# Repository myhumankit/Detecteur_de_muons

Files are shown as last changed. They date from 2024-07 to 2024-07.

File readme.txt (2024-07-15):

This project is an evolution of "CosmicWatch-Desktop-Muon-Detector" published by MIT.
see project description on . 
http://www.cosmicwatch.lns.mit.edu/detector#cosmicwatch

here, the aim was to develop a version of the sensor to support a participatory science program, 
so that it could be taken on board a sailing boat during high-latitude measurement campaigns. 

This new version, developed by My Human Kit , has made it possible to produce and significantly improve the architecture of the sensor 
and its code:
- Evolution of the code so that it can both record data and display it on an OLED screen (whereas MIT proposed 2 different versions of the code). 
- Addition of a GNSS receiver to synchronize data and autonomously record the boat's position 
- Addition of a RTC module to retain date and time in the event of a power cut 
- Improved data display on screen
- Optimization of the detection algo 
- Creation of a python script for data analysis (not yet finished)

my human kit, in carrying out this project, has supported the Astrolabe Expéditions association as part of the "cosmic sail" program.

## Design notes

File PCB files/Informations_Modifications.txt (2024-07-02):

le 19-02-2024
La version "Prod" est celle qui à été envoyée pour la réalisation des pcb.
La version "Fichiers_Eclates" est la version qui à servi à la réalisation des deux boitiers.
Les modifications concernes principalement le schéma et la carte ESP32.

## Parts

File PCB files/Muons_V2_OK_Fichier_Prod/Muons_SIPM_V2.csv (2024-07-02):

Source: | Muons_SIPM_V2 |  |  |  |  |  | Commentaires
Date: | 19/03/2023 14:07:50
Tool: | Eeschema 7.0.1
Generator: | P:\PCB\KiCad60\bin\scripting\plugins/bom_csv_grouped_by_value_with_fp.py
Component Count: | 140
Ref | Qnty | Value | Cmp name | Footprint | Description | Vendor
B1, | 1 | Blindage | Blindage_29.5 | COMPOSANT_CF:Blindage_29.5 | Blindage 29.5v
C1, C3, C5, C7, C8, C11, C14, | 7 | 0.1µF | C_Small | COMPOSANT_CF:C_0805_Muons | Unpolarized capacitor, small symbol
C2, C9, C24, | 3 | 1µF | C_Small | COMPOSANT_CF:C_0805_Muons | Unpolarized capacitor, small symbol
C4, | 1 | 22pF | C_Small | COMPOSANT_CF:C_0805_Muons | Unpolarized capacitor, small symbol
C6, | 1 | 0.47µF | C_Small | COMPOSANT_CF:C_0805_Muons | Unpolarized capacitor, small symbol
C10, C15, C17, C19, C20, C21, C22, | 7 | 10µF | C_Small | COMPOSANT_CF:C_0805_Muons | Unpolarized capacitor, small symbol
C12, | 1 | 10pF | C_Small | COMPOSANT_CF:C_0805_Muons | Unpolarized capacitor, small symbol
C13, | 1 | 20nF | C_Small | COMPOSANT_CF:C_0805_Muons | Unpolarized capacitor, small symbol
C16, C18, C23, C25, C26, | 5 | 100nF | C_Small | COMPOSANT_CF:C_0805_Muons | Unpolarized capacitor, small symbol
Cn1, | 1 | GND | TestPoint | COMPOSANT_CF:TestPoint_THTPad_4.75x3.7mm_Drill1.5mm | test point
D1, D2, D3, | 3 | D_Schottky | D_Schottky | Diode_SMD:D_SOD-123 | Schottky diode
D4, D5, D6, | 3 | MDB301 | MDB301 | Package_TO_SOT_SMD:SOT-23 | 30V 0.1A Small signal Schottky diode, SOT-23
H1, H2, | 2 | SiMP | MountingHole_Pad | MountingHole:MountingHole_2.2mm_M2_DIN965_Pad_TopBottom | Mounting Hole with connection
H3, H4, H5, H6, | 4 | Board_SiMP | MountingHole_Pad | MountingHole:MountingHole_2.2mm_M2_DIN965_Pad_TopBottom | Mounting Hole with connection
H7, H8, H9, H13, H14, | 5 | ESP | MountingHole_Pad | MountingHole:MountingHole_2.2mm_M2_DIN965_Pad_TopBottom | Mounting Hole with connection
H10, H11, H12, | 3 | RTC | MountingHole_Pad | MountingHole:MountingHole_2.2mm_M2_DIN965_Pad_TopBottom | Mounting Hole with connection
IC1, | 1 | BMP280_AZ | BMP280_AZ | COMPOSANT_CF:BMP280_AZ | Pressure Sensor Development Tools Barometric Pressure & Altitude Sensor
J1, | 1 | WM17457-ND | Conn_02x03_Odd_Even | Connector_PinSocket_2.54mm:PinSocket_2x03_P2.54mm_Vertical | Generic connector, double row, 02x03, odd/even pin numbering scheme (row 1 odd numbers, row 2 even numbers), script generated (kicad-library-utils/schlib/autogen/connector/)
J2, J4, | 2 | 221790-1 | 221790-1_1 | COMPOSANT_CF:TE_221790-1
J3, | 1 | DB9 F Chassi | DE9_Receptacle | Connector_Dsub:DSUB-9_Female_Horizontal_P2.77x2.84mm_EdgePinOffset4.94mm_Housed_MountingHolesOffset7.48mm | 9-pin female receptacle socket D-SUB connector, Mounting Hole
J5, | 1 | Conn_01x07_Socket | Conn_01x07_Socket | Connector_Molex:Molex_KK-254_AE-6410-07A_1x07_P2.54mm_Vertical | Generic connector, single row, 01x07, script generated
J6, | 1 | Conn_01x06_Socket | Conn_01x06_Socket | Connector_Molex:Molex_KK-254_AE-6410-06A_1x06_P2.54mm_Vertical | Generic connector, single row, 01x06, script generated
J7, | 1 | Conn_01x08_Socket | Conn_01x08_Socket | Connector_Molex:Molex_KK-254_AE-6410-08A_1x08_P2.54mm_Vertical | Generic connector, single row, 01x08, script generated
J8, | 1 | Depuis le board SIPM | Conn_01x08_Socket | Connector_Molex:Molex_KK-254_AE-6410-08A_1x08_P2.54mm_Vertical | Generic connector, single row, 01x08, script generated
J9, | 1 | Depuis le board SIPM | Conn_01x03_Socket | Connector_Molex:Molex_KK-254_AE-6410-03A_1x03_P2.54mm_Vertical | Generic connector, single row, 01x03, script generated
J10, | 1 | Vers Pcb GPS | Conn_01x06_Socket | Connector_Molex:Molex_KK-254_AE-6410-06A_1x06_P2.54mm_Vertical | Generic connector, single row, 01x06, script generated
J11, | 1 | Vers Pcb Gps | Conn_01x07_Socket | Connector_Molex:Molex_KK-254_AE-6410-07A_1x07_P2.54mm_Vertical | Generic connector, single row, 01x07, script generated
J12, | 1 | Conn_01x08_Socket | Conn_01x08_Socket | Connector_PinSocket_2.54mm:PinSocket_1x08_P2.54mm_Vertical | Generic connector, single row, 01x08, script generated
J13, | 1 | Conn_01x08_Socket | Conn_01x08_Socket | Connector_PinHeader_2.54mm:PinHeader_1x08_P2.54mm_Vertical | Generic connector, single row, 01x08, script generated
J14, | 1 | Oled | Conn_01x04_Socket | COMPOSANT_CF:OLED_PCB | Generic connector, single row, 01x04, script generated
J15, | 1 | Micro_SD_Card | Micro_SD_Card | COMPOSANT_CF:SD-CARD_AZ | Micro SD Card Socket
K1, | 1 | G3VM-21GR1 | G3VM-21GR1 | COMPOSANT_CF:G3VM-21GR1
K2, | 1 | G3VM-41DY | G3VM-41DY | COMPOSANT_CF:RELAY_G3VM-41DY
K3, | 1 | G3VM-81UR | G3VM-81UR | COMPOSANT_CF:G3VM-81UR
L1, | 1 | Ferrite Bead | L | Resistor_SMD:R_0805_2012Metric_Pad1.20x1.40mm_HandSolder | Inductor
L2, | 1 | 47ÂµH | L | Resistor_SMD:R_1210_3225Metric_Pad1.30x2.65mm_HandSolder | Inductor
Led1, | 1 | Double Led | Double_Led | COMPOSANT_CF:Double_Led | Buzzer, polarized
M1, | 1 | DS3231 | DS3231 | COMPOSANT_CF:REG_DS3231_2023
M2, | 1 | ESP_WROOM_32_38b | ESP_WROOM_32 | COMPOSANT_CF:MODULE_ESP32-DEVKITC
Q1, | 1 | BMBT3904 | PMBT3904 | Package_TO_SOT_SMD:SOT-323_SC-70 | 0.8A Ic, 45V Vce, NPN Transistor, SOT-323
Q2, | 1 | BSS138 | BSS138 | Package_TO_SOT_SMD:SOT-23 | 50V Vds, 0.22A Id, N-Channel MOSFET, SOT-23
R1, R6, R10, R13, R14, R16, R17, R18, R19, R20, R21, | 11 | 10k | R_Small | COMPOSANT_CF:R_0805_Muons | Resistor, small symbol
R2, | 1 | 226k | R_Small | COMPOSANT_CF:R_0805_Muons | Resistor, small symbol
R3, R4, R8, R9, R12, R15, R23, R24, R26, R27, | 10 | 1k | R | COMPOSANT_CF:R_0805_Muons | Resistor
R5, | 1 | 7.5k | R_Small | COMPOSANT_CF:R_0805_Muons | Resistor, small symbol
R7, R22, R29, R30, R31, | 5 | 100k | R | COMPOSANT_CF:R_0805_Muons | Resistor
R11, | 1 | 4.7M | R_Small | COMPOSANT_CF:R_0805_Muons | Resistor, small symbol
R25, | 1 | 3.3k | R | COMPOSANT_CF:R_0805_Muons | Resistor
R28, | 1 | 4.7k | R | COMPOSANT_CF:R_0805_Muons | Resistor
R32, | 1 | 360 | R_Small | COMPOSANT_CF:R_0805_Muons | Resistor, small symbol
R33, R34, | 2 | 0 | R | COMPOSANT_CF:R_Shunt_0805_Muons | Resistor
R35, R36, R37, R38, | 4 | 47k | R | COMPOSANT_CF:R_0805_Muons | Resistor
R39, R40, | 2 | 330 | R_Small | COMPOSANT_CF:R_0805_Muons | Resistor, small symbol
RV1, RV2, | 2 | 4.7k | R_Potentiometer_Trim | Potentiometer_THT:Potentiometer_Bourns_3005_Horizontal | Trim-potentiometer
RV3, RV4, | 2 | 5k | R_Potentiometer_Trim | Potentiometer_SMD:Potentiometer_Bourns_3314G_Vertical | Trim-potentiometer
SW1, | 1 | Ajust_Time | SW_MEC_5G | Button_Switch_THT:SW_Tactile_SPST_Angled_PTS645Vx83-2LFS | MEC 5G single pole normally-open tactile switch
SW2, | 1 | SW_Coded_SH-7010 | SW_Coded_SH-7010 | COMPOSANT_CF:Nidec_Copal_SC-1110 | Rotary switch, 4-bit encoding, 10 positions, Real code
TP1, TP2, | 2 | s1 | TestPoint | COMPOSANT_CF:TestPoint_THTPad_4.75x3.7mm_Drill1.5mm | test point
TP3, | 1 | GND3 | TestPoint | COMPOSANT_CF:TestPoint_THTPad_4.75x3.7mm_Drill1.5mm | test point
TP4, TP5, TP6, TP7, | 4 | GND1 | TestPoint | COMPOSANT_CF:TestPoint_THTPad_4.75x3.7mm_Drill1.5mm | test point
TP8, | 1 | GND2 | TestPoint | COMPOSANT_CF:TestPoint_THTPad_4.75x3.7mm_Drill1.5mm | test point
U1, | 1 | LT3461 | LT3461 | Package_TO_SOT_SMD:TSOT-23-6 | 1.2MHz White LED Drivers with Built-in Schottky, ThinSOT-23-6
U2, | 1 | AD823A | AD823A | Package_SO:SOIC-8_3.9x4.9mm_P1.27mm | Dual Operational Amplifiers, DIP-8/SOIC-8/TSSOP-8/VSSOP-8
U3, U4, | 2 | LT1806 | LT1806 | Package_SO:SOIC-8_3.9x4.9mm_P1.27mm | Ultra-Low Offset/Drift, Low-Noise, Precision Amplifiers, SOIC-8
U5, | 1 | DS18B20 | DS18B20 | Package_TO_SOT_THT:TO-92_Inline | Programmable Resolution 1-Wire Digital Thermometer TO-92
U6, | 1 | NEO-M8N | NEO-M8N | MODULE_CF:GPS_NEO8 | GNSS Module NEO M8, VCC 2.7V to 3.6V
U7, | 1 | LM311 | LM311 | Package_SO:SOIC-8_3.9x4.9mm_P1.27mm | Voltage Comparator, DIP-8/SOIC-8
U8, | 1 | MAX988EUK+ | MAX988EUK+ | COMPOSANT_CF:SOT95P280X145-5N
U9, | 1 | GT1167 | GT1167 | COMPOSANT_CF:DIP-12_Convertisseur | Convertisseur de niveau logic 2 canaux 3v3 5v
U10, | 1 | ADC_Breakout_ADS1015 | ADC_Breakout_ADS1115 | MODULE_CF:ADS1115_Small_BreakBord
U11, | 1 | G3VM-101DR1 | G3VM-101DR1(TR05) | COMPOSANT_CF:G3VM-21GR1
U12, | 1 | Regul3.3v | Regul3.3v | COMPOSANT_CF:Regulateur | 1A Low Dropout regulator, positive, adjustable output, TO-252

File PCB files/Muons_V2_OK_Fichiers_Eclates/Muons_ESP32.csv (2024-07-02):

Source: | I:\PCB\KiCad\MUONS v2\Muons_V3\Muons_ESP32.kicad_sch
Date: | 30/04/2023 09:25:12
Tool: | Eeschema 7.0.1
Generator: | P:\PCB\KiCad51101\bin\scripting\plugins/bom_csv_grouped_by_value_with_fp.py
Component Count: | 48
Ref | Qnty | Value | Cmp name | Footprint | Description | Vendor
C19, C20, C21, C22, | 4 | 10µF | C_Small | COMPOSANT_CF:C_0805_Muons | Unpolarized capacitor, small symbol
C23, C25, C26, | 3 | 100nF | C_Small | COMPOSANT_CF:C_0805_Muons | Unpolarized capacitor, small symbol
C24, | 1 | 1µF | C_Small | COMPOSANT_CF:C_0805_Muons | Unpolarized capacitor, small symbol
H7, H8, H9, H14, | 4 | ESP | MountingHole_Pad | MountingHole:MountingHole_2.2mm_M2_DIN965_Pad_TopBottom | Mounting Hole with connection
H15, H16, | 2 | ESP | MountingHole_Pad_2 | COMPOSANT_CF:MountingHole_2.2mm_M2 | Mounting Hole with connection
J8, | 1 | Depuis le board SIPM | Conn_01x08_Socket | Connector_Molex:Molex_KK-254_AE-6410-08A_1x08_P2.54mm_Vertical | Generic connector, single row, 01x08, script generated
J9, | 1 | Depuis le board SIPM | Conn_01x03_Socket | Connector_Molex:Molex_KK-254_AE-6410-03A_1x03_P2.54mm_Vertical | Generic connector, single row, 01x03, script generated
J10, | 1 | Vers Pcb GPS | Conn_01x06_Socket | Connector_Molex:Molex_KK-254_AE-6410-06A_1x06_P2.54mm_Vertical | Generic connector, single row, 01x06, script generated
J11, | 1 | Vers Pcb Gps | Conn_01x07_Socket | Connector_Molex:Molex_KK-254_AE-6410-07A_1x07_P2.54mm_Vertical | Generic connector, single row, 01x07, script generated
J13, | 1 | Conn_01x08_Socket | Conn_01x08_Socket | Connector_PinHeader_2.54mm:PinHeader_1x08_P2.54mm_Vertical | Generic connector, single row, 01x08, script generated
Led1, | 1 | Double Led | Double_Led | COMPOSANT_CF:Double_Led | Buzzer, polarized
M2, | 1 | ESP_WROOM_32_38b_AZ | ESP_WROOM_32_38b_AZ | COMPOSANT_CF:MODULE_ESP32-DEVKITC
R27, | 1 | 1k | R | COMPOSANT_CF:R_0805_Muons | Resistor
R28, | 1 | 4.7k | R | COMPOSANT_CF:R_0805_Muons | Resistor
R29, R30, R31, | 3 | 100k | R | COMPOSANT_CF:R_0805_Muons | Resistor
R32, | 1 | 360 | R_Small | COMPOSANT_CF:R_0805_Muons | Resistor, small symbol
R33, R34, | 2 | 0 | R | COMPOSANT_CF:R_Shunt_0805_Muons | Resistor
R35, R36, R37, R38, | 4 | 47k | R | COMPOSANT_CF:R_0805_Muons | Resistor
R39, R40, | 2 | 330 | R_Small | COMPOSANT_CF:R_0805_Muons | Resistor, small symbol
R41, | 1 | 47k | R | COMPOSANT_CF:R_Shunt_0805_Muons | Resistor
RV4, | 1 | 5k | R_Potentiometer_Trim | Potentiometer_SMD:Potentiometer_Bourns_3314G_Vertical | Trim-potentiometer
SW1, | 1 | Ajust_Time | SW_MEC_5G | Button_Switch_THT:SW_Tactile_SPST_Angled_PTS645Vx83-2LFS | MEC 5G single pole normally-open tactile switch
SW2, | 1 | SW_Coded_SH-7010 | SW_Coded_SH-7010 | COMPOSANT_CF:Nidec_Copal_SC-1110 | Rotary switch, 4-bit encoding, 10 positions, Real code
SW3, | 1 | SW_SPDT | SW_SPDT | COMPOSANT_CF:Sw_sil | Switch, single pole double throw
TP4, TP5, TP6, TP7, | 4 | GND1 | TestPoint | COMPOSANT_CF:TestPoint_THTPad_4.75x3.7mm_Drill1.5mm | test point
U9, | 1 | GT1167 | GT1167 | COMPOSANT_CF:DIP-12_Convertisseur | Convertisseur de niveau logic 2 canaux 3v3 5v
U10, | 1 | ADC_Breakout_ADS1015 | ADC_Breakout_ADS1115 | MODULE_CF:ADS1115_Small_BreakBord
U11, | 1 | G3VM-41DY | TLP241 | COMPOSANT_CF:G3VM-21GR1
U12, | 1 | Regul3.3v | Regul3.3v | COMPOSANT_CF:Regulateur | 1A Low Dropout regulator, positive, adjustable output, TO-252

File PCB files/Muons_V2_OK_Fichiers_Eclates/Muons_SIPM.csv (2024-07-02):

Source: | I:\PCB\KiCad\MUONS v2\Muons_V3\Muons_SIPM.kicad_sch
Date: | 30/04/2023 09:02:18
Tool: | Eeschema 7.0.1
Generator: | P:\PCB\KiCad60\bin\scripting\plugins/bom_csv_grouped_by_value_with_fp.py
Component Count: | 75
Ref | Qnty | Value | Cmp name | Footprint | Description | Vendor
B1, | 1 | Blindage | Blindage_29.5 | COMPOSANT_CF:Blindage_29.5 | Blindage 29.5v
C1, C3, C5, C7, C8, C11, C14, | 7 | 0.1ÂµF | C_Small | COMPOSANT_CF:C_0805_Muons | Unpolarized capacitor, small symbol
C2, C9, | 2 | 1ÂµF | C_Small | COMPOSANT_CF:C_0805_Muons | Unpolarized capacitor, small symbol
C4, | 1 | 22pF | C_Small | COMPOSANT_CF:C_0805_Muons | Unpolarized capacitor, small symbol
C6, | 1 | 0.47ÂµF | C_Small | COMPOSANT_CF:C_0805_Muons | Unpolarized capacitor, small symbol
C10, C15, | 2 | 10ÂµF | C_Small | COMPOSANT_CF:C_0805_Muons | Unpolarized capacitor, small symbol
C12, | 1 | 10pF | C_Small | COMPOSANT_CF:C_0805_Muons | Unpolarized capacitor, small symbol
C13, | 1 | 4.7nF | C_Small | COMPOSANT_CF:C_0805_Muons | Unpolarized capacitor, small symbol
C16, | 1 | 100nF | C | COMPOSANT_CF:C_0805_Muons | Unpolarized capacitor
Cn1, | 1 | GND | TestPoint | COMPOSANT_CF:TestPoint_THTPad_4.75x3.7mm_Drill1.5mm | test point
D1, D2, | 2 | BAT54 | D_Schottky | Diode_SMD:D_SOD-123 | Schottky diode
D3, | 1 | D_Schottky | D_Schottky | Resistor_SMD:R_1206_3216Metric_Pad1.30x1.75mm_HandSolder | Schottky diode
D4, D5, D6, | 3 | MDB301 | MDB301 | Package_TO_SOT_SMD:SOT-23 | 30V 0.1A Small signal Schottky diode, SOT-23
H1, H2, | 2 | SiMP | MountingHole_Pad | MountingHole:MountingHole_2.2mm_M2_DIN965_Pad_TopBottom | Mounting Hole with connection
H3, H4, H5, H6, | 4 | Board_SiMP | MountingHole_Pad | MountingHole:MountingHole_2.2mm_M2_DIN965_Pad_TopBottom | Mounting Hole with connection
J1, | 1 | WM17457-ND | Conn_02x03_Odd_Even | Connector_PinSocket_2.54mm:PinSocket_2x03_P2.54mm_Vertical | Generic connector, double row, 02x03, odd/even pin numbering scheme (row 1 odd numbers, row 2 even numbers), script generated (kicad-library-utils/schlib/autogen/connector/)
J2, | 1 | 221790-1 | 221790-1 | COMPOSANT_CF:TE_221790-1
J7, | 1 | Conn_01x08_Socket | Conn_01x08_Socket | Connector_Molex:Molex_KK-254_AE-6410-08A_1x08_P2.54mm_Vertical | Generic connector, single row, 01x08, script generated
K1, | 1 | G3VM-21GR1 | G3VM-21GR1 | COMPOSANT_CF:G3VM-21GR1
K2, | 1 | G3VM-41DY | G3VM-41DY | COMPOSANT_CF:RELAY_G3VM-41DY
K3, | 1 | G3VM-81UR | G3VM-81UR | COMPOSANT_CF:G3VM-81UR
L1, | 1 | Ferrite Bead | L | Resistor_SMD:R_0805_2012Metric_Pad1.20x1.40mm_HandSolder | Inductor
L2, | 1 | 47ÂµH | L | Resistor_SMD:R_1210_3225Metric_Pad1.30x2.65mm_HandSolder | Inductor
Q1, | 1 | BMBT3904 | PMBT3904 | Package_TO_SOT_SMD:SOT-323_SC-70 | 0.8A Ic, 45V Vce, NPN Transistor, SOT-323
Q2, | 1 | BSS138 | BSS138 | Package_TO_SOT_SMD:SOT-23 | 50V Vds, 0.22A Id, N-Channel MOSFET, SOT-23
R1, R6, R13, R14, R16, R17, R18, | 7 | 10k | R_Small | COMPOSANT_CF:R_0805_Muons | Resistor, small symbol
R2, | 1 | 226k | R_Small | COMPOSANT_CF:R_0805_Muons | Resistor, small symbol
R3, R4, R8, R9, R15, R23, R24, R26, | 8 | 1k | R | COMPOSANT_CF:R_0805_Muons | Resistor
R5, | 1 | 7.5k | R_Small | COMPOSANT_CF:R_0805_Muons | Resistor, small symbol
R7, R22, | 2 | 100k | R | COMPOSANT_CF:R_0805_Muons | Resistor
R10, R19, R20, R21, | 4 | 470 | R_Small | COMPOSANT_CF:R_0805_Muons | Resistor, small symbol
R11, | 1 | 4.7M | R_Small | COMPOSANT_CF:R_0805_Muons | Resistor, small symbol
R12, R27, | 2 | 0 | R | COMPOSANT_CF:R_0805_Muons | Resistor
R25, | 1 | 3.3k | R | COMPOSANT_CF:R_0805_Muons | Resistor
RV3, | 1 | 5k | R_Potentiometer_Trim | Potentiometer_SMD:Potentiometer_Bourns_3314G_Vertical | Trim-potentiometer
U1, | 1 | LT3461 | LT3461 | Package_TO_SOT_SMD:TSOT-23-6 | 1.2MHz White LED Drivers with Built-in Schottky, ThinSOT-23-6
U2, | 1 | AD823A | AD823A | Package_SO:SOIC-8_3.9x4.9mm_P1.27mm | Dual Operational Amplifiers, DIP-8/SOIC-8/TSSOP-8/VSSOP-8
U3, U4, | 2 | LT1806 | LT1806 | Package_SO:SOIC-8_3.9x4.9mm_P1.27mm | Ultra-Low Offset/Drift, Low-Noise, Precision Amplifiers, SOIC-8
U5, | 1 | DS18B20 | DS18B20 | Package_TO_SOT_THT:TO-92_Inline | Programmable Resolution 1-Wire Digital Thermometer TO-92
U7, | 1 | LM311 | LM311 | Package_SO:SOIC-8_3.9x4.9mm_P1.27mm | Voltage Comparator, DIP-8/SOIC-8
U8, | 1 | MAX988EUK+ | MAX988EUK+ | COMPOSANT_CF:SOT95P280X145-5N

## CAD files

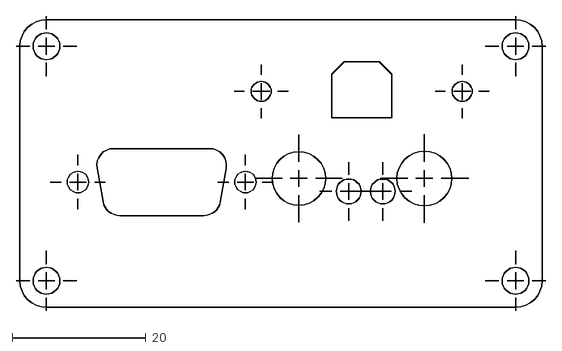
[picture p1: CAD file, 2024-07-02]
3D Models/Plaque_AR_V3_CNC.dxf
79.0 x 44.0

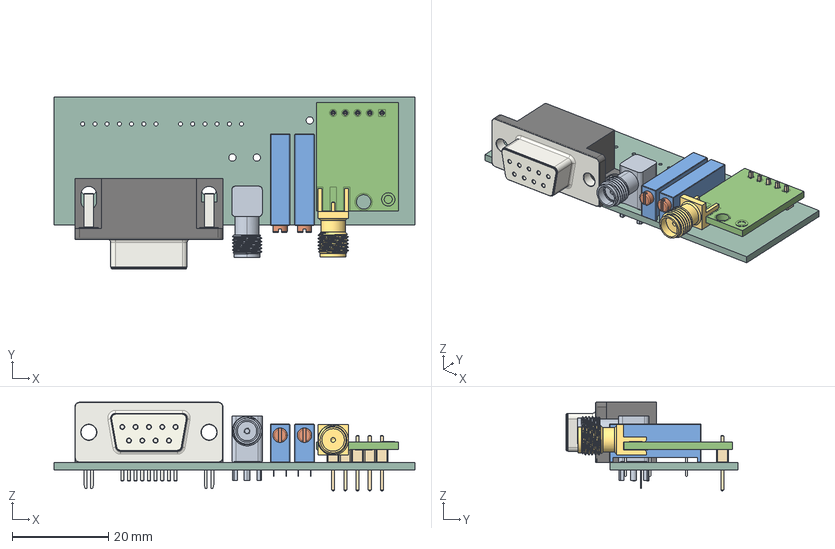
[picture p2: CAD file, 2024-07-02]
PCB files/Muons_V2_OK_Fichiers_Eclates/Muons_GPS.step
75.0 x 35.7 x 18.4 mm
PCB

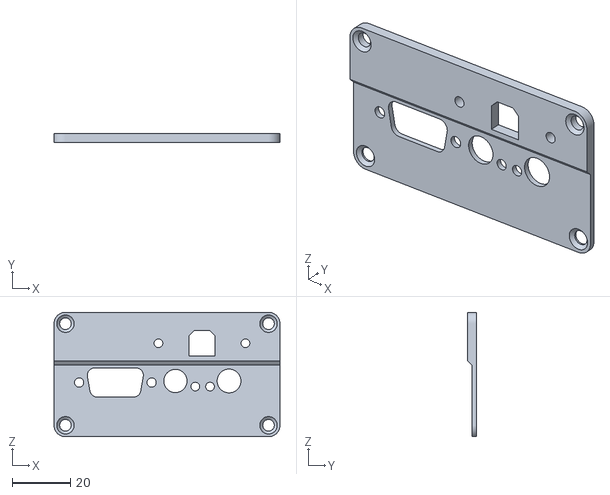
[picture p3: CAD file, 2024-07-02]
3D Models/Plaque_AR_V2.stl
77.9 x 3.00 x 42.9

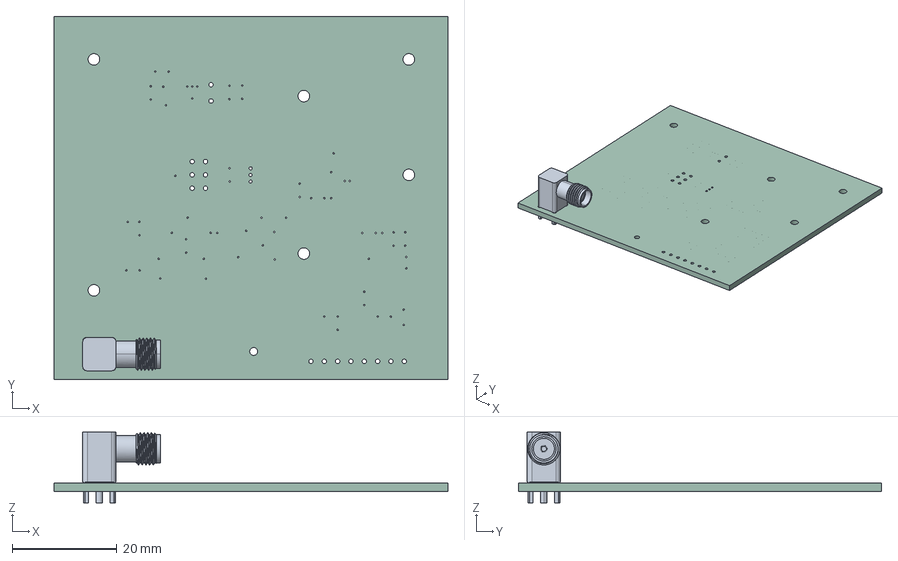
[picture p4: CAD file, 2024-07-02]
PCB files/Muons_V2_OK_Fichiers_Eclates/Muons_SIPM.step
75.0 x 69.2 x 13.5 mm
PCB

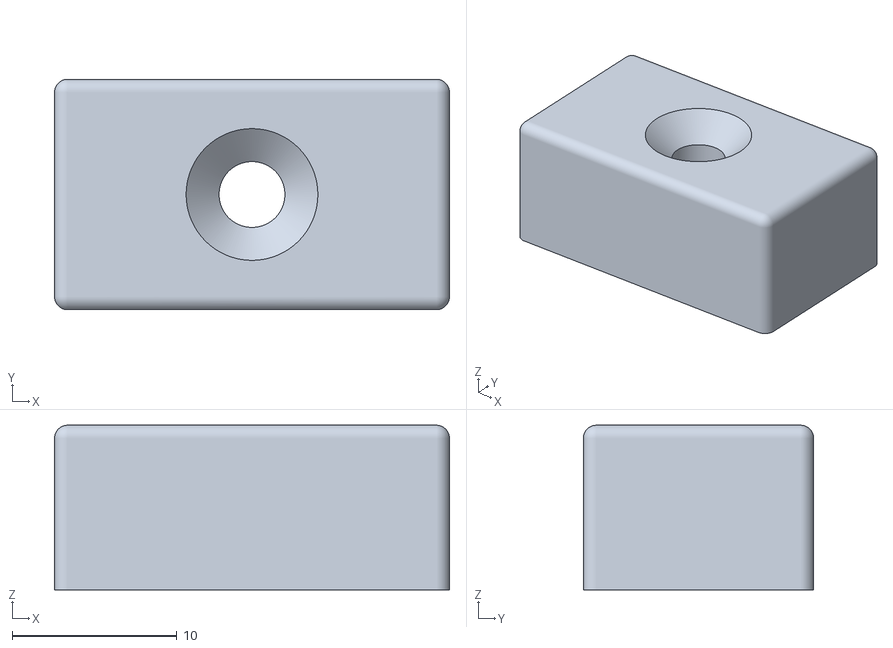
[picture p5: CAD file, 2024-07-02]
3D Models/Forme_Blindage.stl
24.0 x 14.0 x 10.0

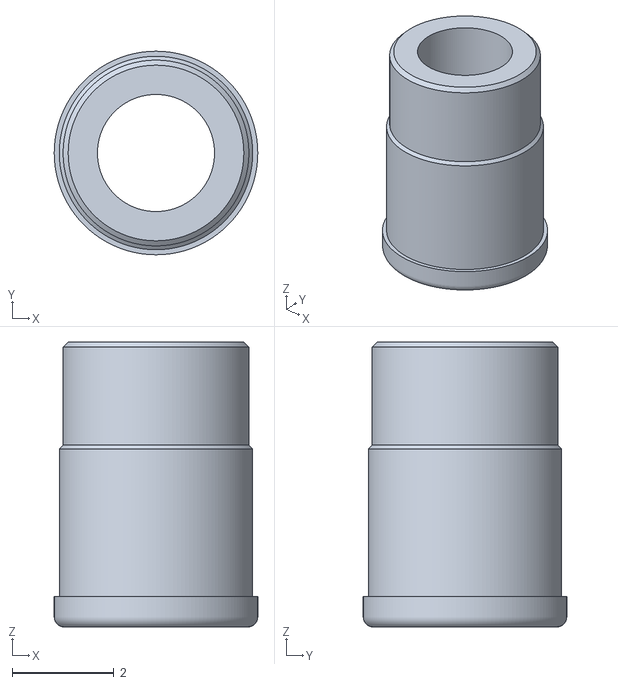
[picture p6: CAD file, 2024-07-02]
3D Models/Guide_Trim.stl
4.00 x 4.00 x 5.60

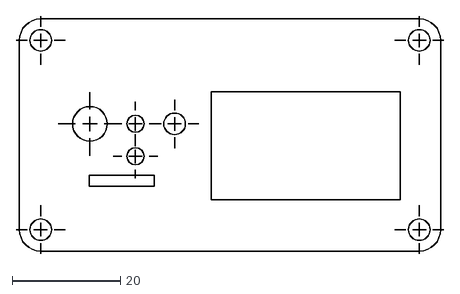
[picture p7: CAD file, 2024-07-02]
3D Models/Plaque_AV_V3_CNC.dxf
79.0 x 44.0

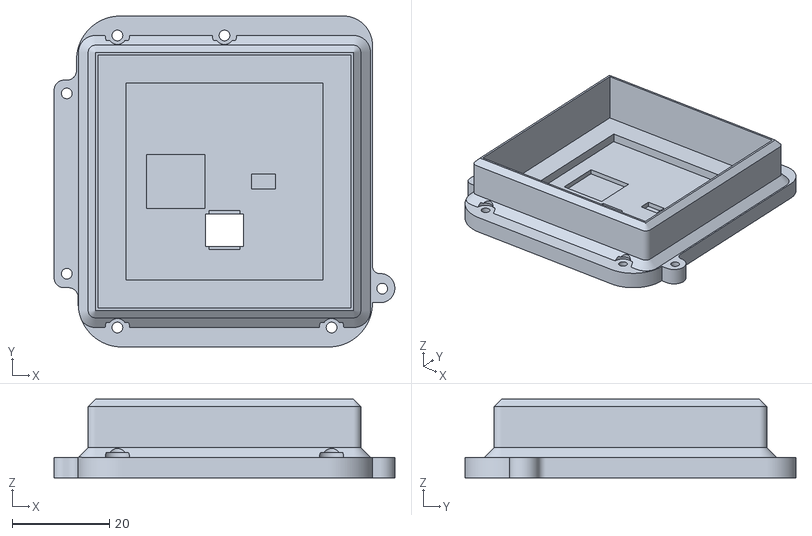
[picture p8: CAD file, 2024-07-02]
3D Models/Boitier_V4_b.stl
70.0 x 68.0 x 16.2

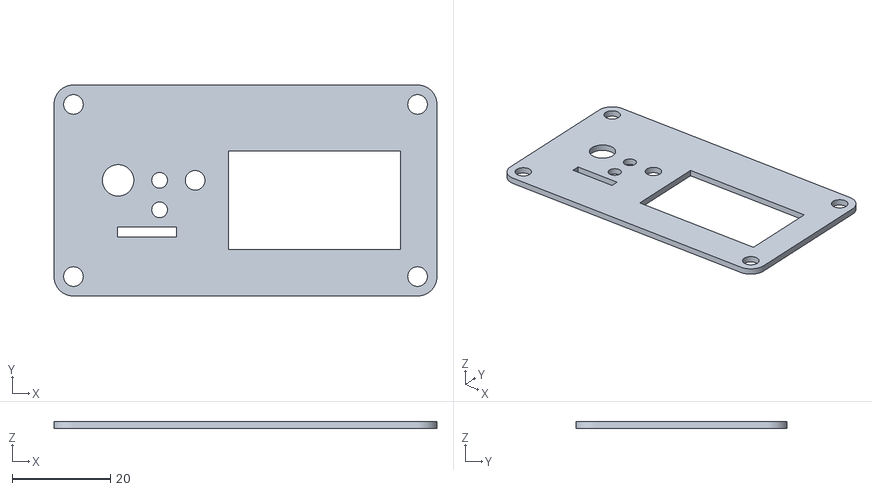
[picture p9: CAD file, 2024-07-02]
3D Models/Plaque_AV_V3.stl
77.9 x 42.9 x 1.50

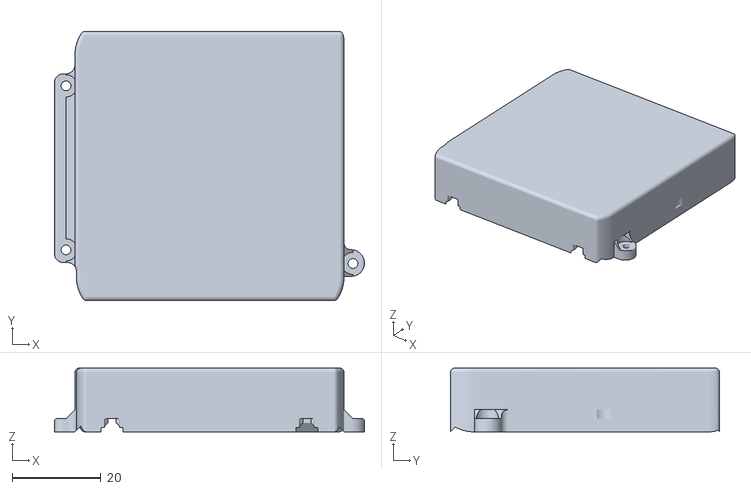
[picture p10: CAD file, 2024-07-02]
3D Models/Couvercle_V4_b.stl
70.0 x 60.8 x 14.4

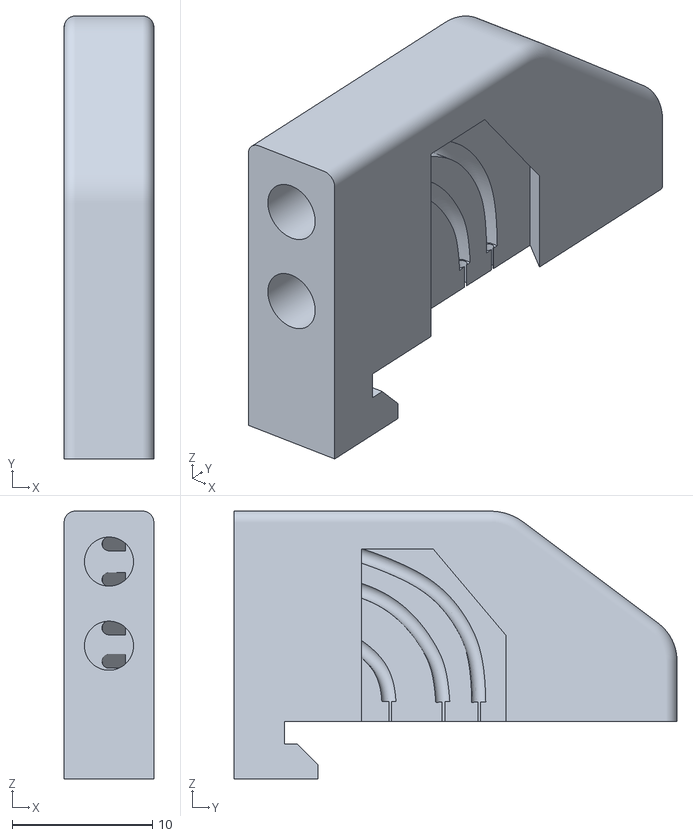
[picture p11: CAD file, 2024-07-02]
3D Models/Porte_Led_v4.stl
6.40 x 31.6 x 19.1

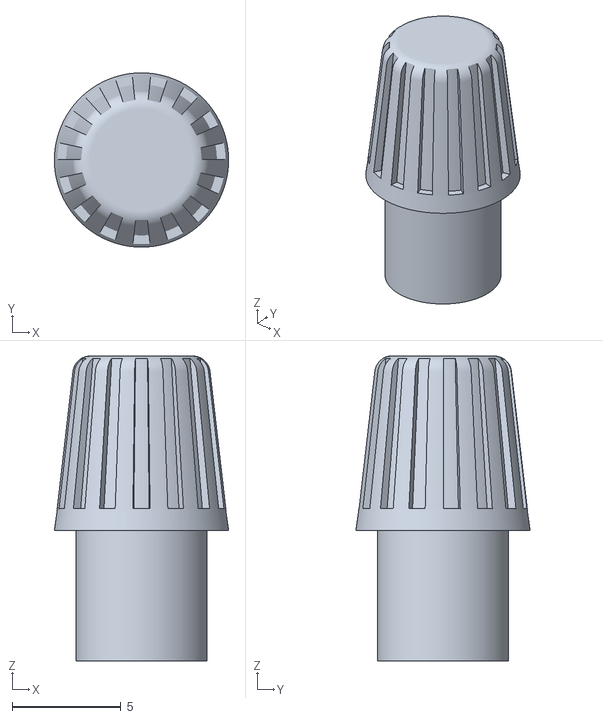
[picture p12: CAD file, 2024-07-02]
3D Models/Bouton_V4_b.stl
8.00 x 8.00 x 14.0

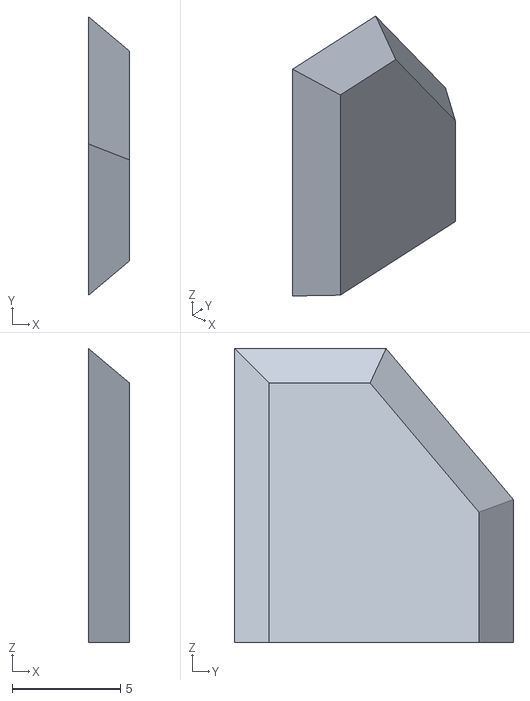
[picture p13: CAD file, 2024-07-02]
3D Models/Trappe_v4.stl
1.90 x 12.9 x 13.6

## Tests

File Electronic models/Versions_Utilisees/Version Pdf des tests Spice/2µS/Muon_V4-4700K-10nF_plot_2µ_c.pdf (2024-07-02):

0µs | 80µs | 160µs | 240µs | 320µs | 400µs | 480µs | 560µs | 640µs | 720µs | 800µs

0.0V

0.2V

0.4V

0.6V

0.8V

1.0V

1.2V

1.4V

1.6V

1.8V

V(n003) | V(n002) | V(out_peak_detect)

### --- I:\FRANCOIS\MUON\Muons_V4_a.raw ---

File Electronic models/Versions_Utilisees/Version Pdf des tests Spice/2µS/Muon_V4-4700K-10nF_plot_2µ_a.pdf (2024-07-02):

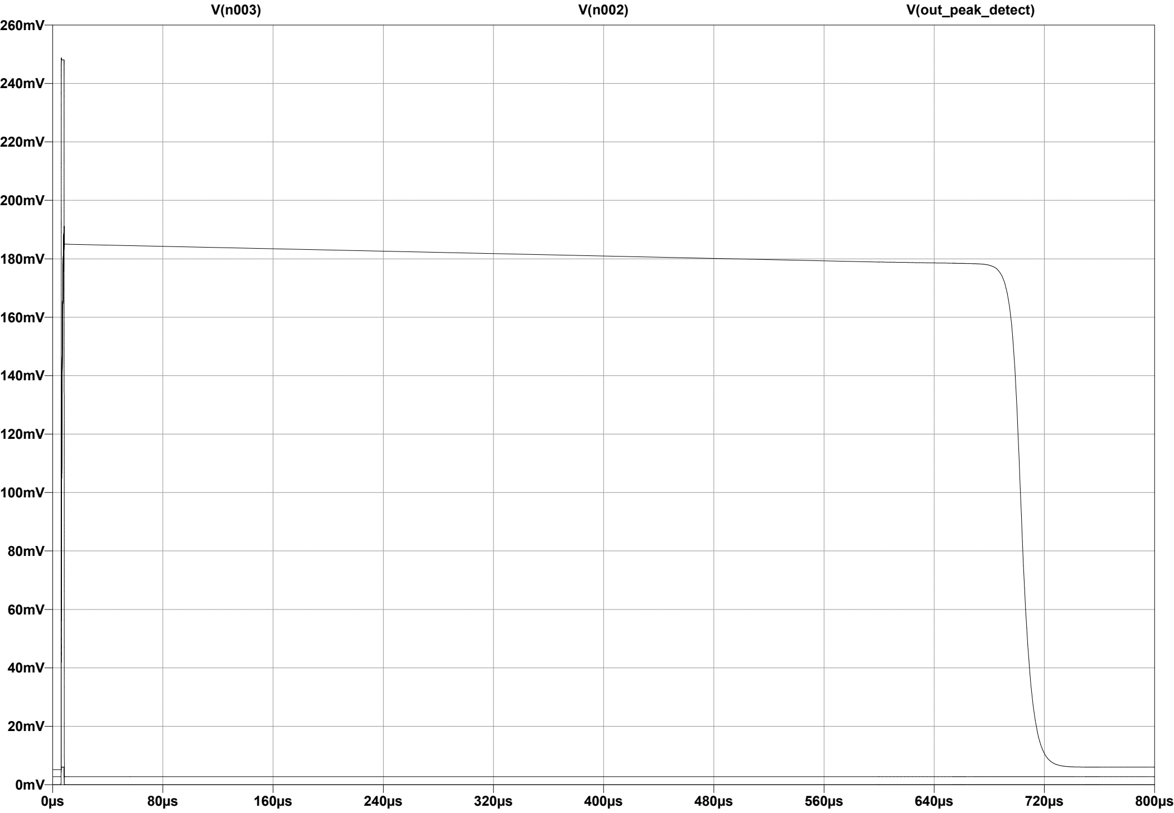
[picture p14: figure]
V(out_peak_detect)

0µs | 80µs | 160µs | 240µs | 320µs | 400µs | 480µs | 560µs | 640µs | 720µs | 800µs

### --- I:\FRANCOIS\MUON\Muons_V4_a.raw ---

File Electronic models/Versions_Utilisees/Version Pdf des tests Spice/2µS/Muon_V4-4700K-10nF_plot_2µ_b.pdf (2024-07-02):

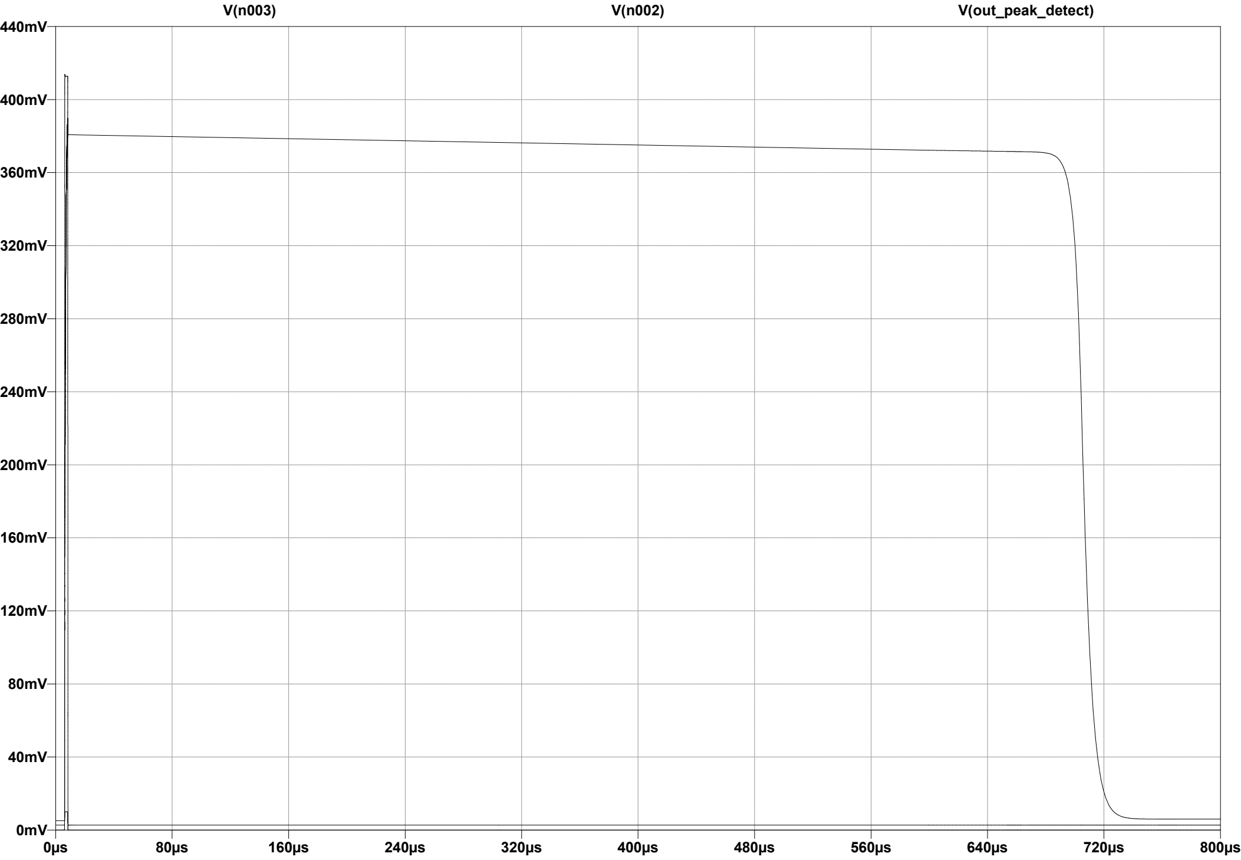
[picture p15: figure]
V(out_peak_detect)

### --- I:\FRANCOIS\MUON\Muons_V4_a.raw ---

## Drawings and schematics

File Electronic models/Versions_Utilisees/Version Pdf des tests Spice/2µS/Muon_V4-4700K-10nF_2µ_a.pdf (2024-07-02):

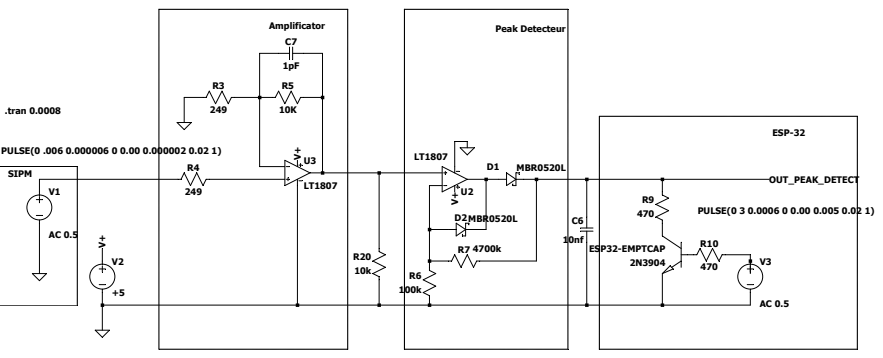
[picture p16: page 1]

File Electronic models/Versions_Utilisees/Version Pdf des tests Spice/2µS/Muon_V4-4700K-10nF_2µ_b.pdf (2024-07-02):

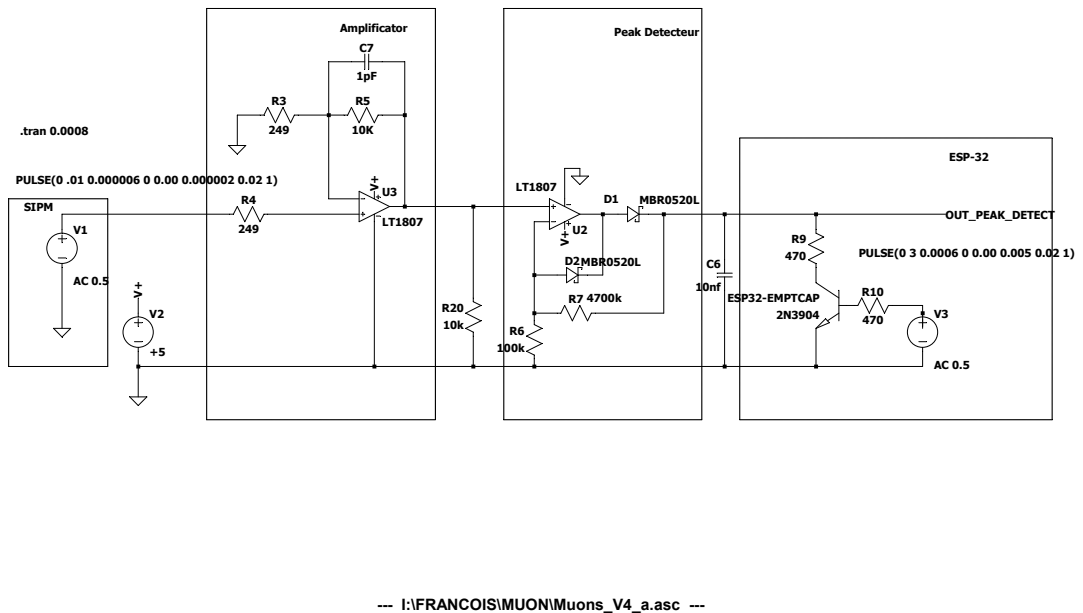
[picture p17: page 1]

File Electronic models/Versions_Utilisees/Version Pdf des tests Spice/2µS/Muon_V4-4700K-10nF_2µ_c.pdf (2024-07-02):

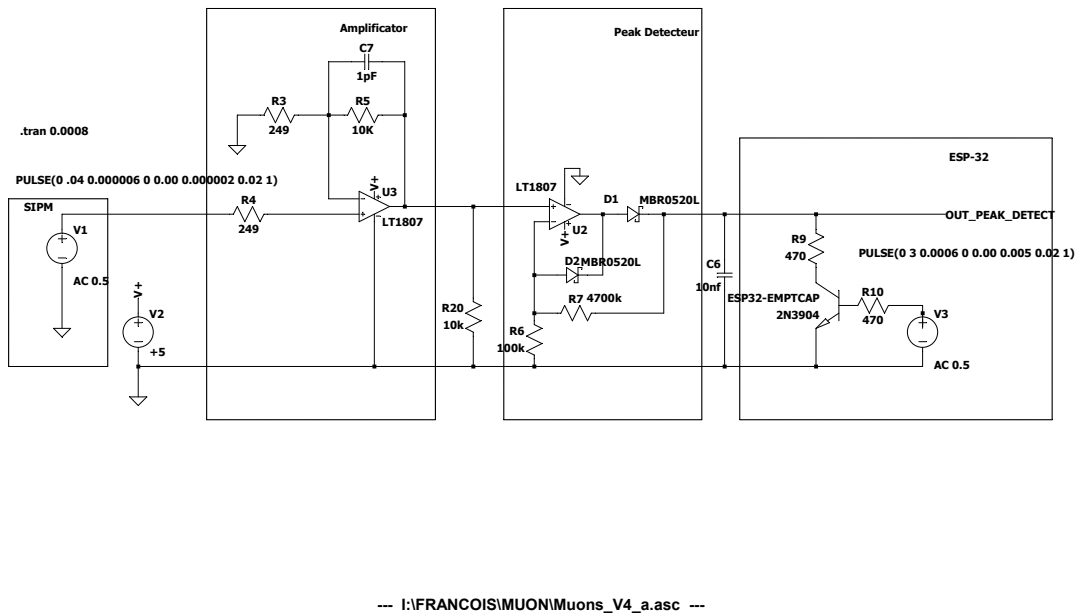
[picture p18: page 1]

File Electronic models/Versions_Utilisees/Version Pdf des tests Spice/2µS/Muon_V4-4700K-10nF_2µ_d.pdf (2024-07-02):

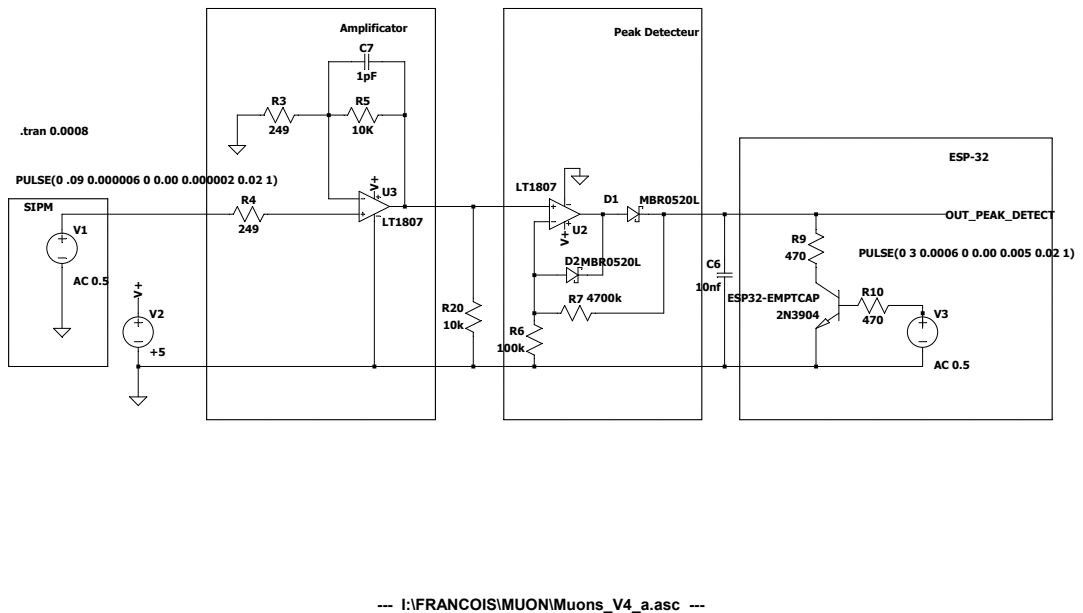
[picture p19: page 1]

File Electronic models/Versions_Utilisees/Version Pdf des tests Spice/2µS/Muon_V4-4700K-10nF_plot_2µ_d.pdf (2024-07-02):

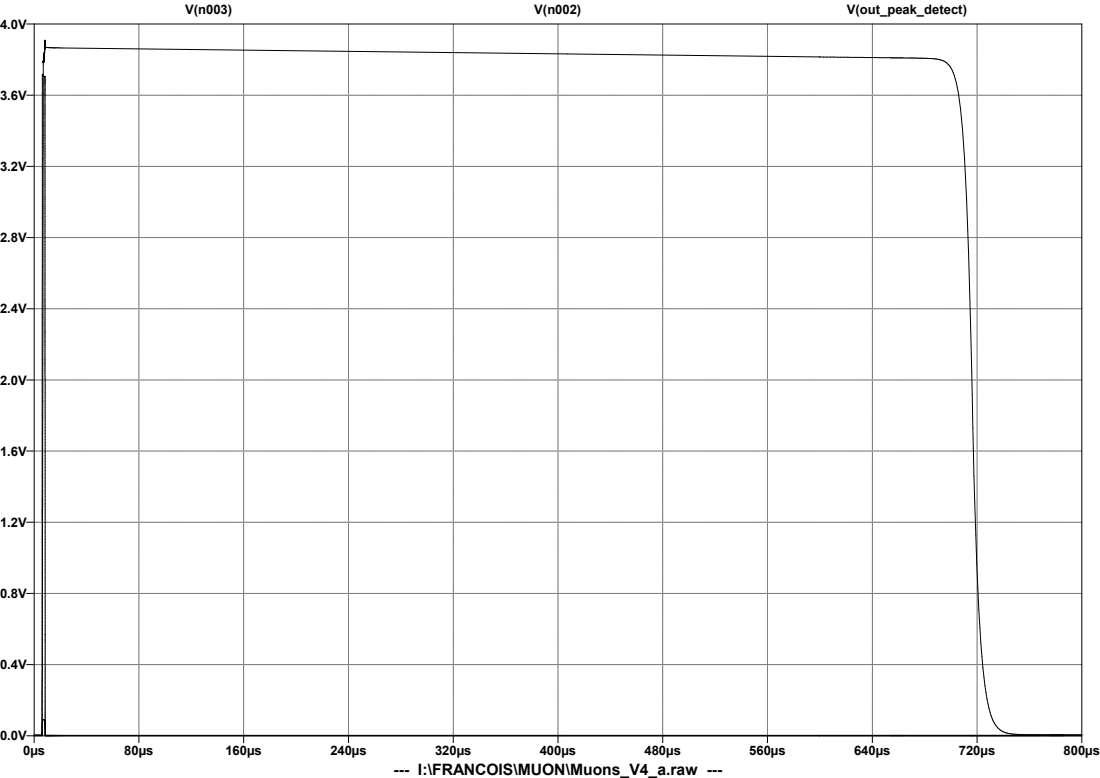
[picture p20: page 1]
V(out_peak_detect)

--- I:\FRANCOIS\MUON\Muons_V4_a.raw ---

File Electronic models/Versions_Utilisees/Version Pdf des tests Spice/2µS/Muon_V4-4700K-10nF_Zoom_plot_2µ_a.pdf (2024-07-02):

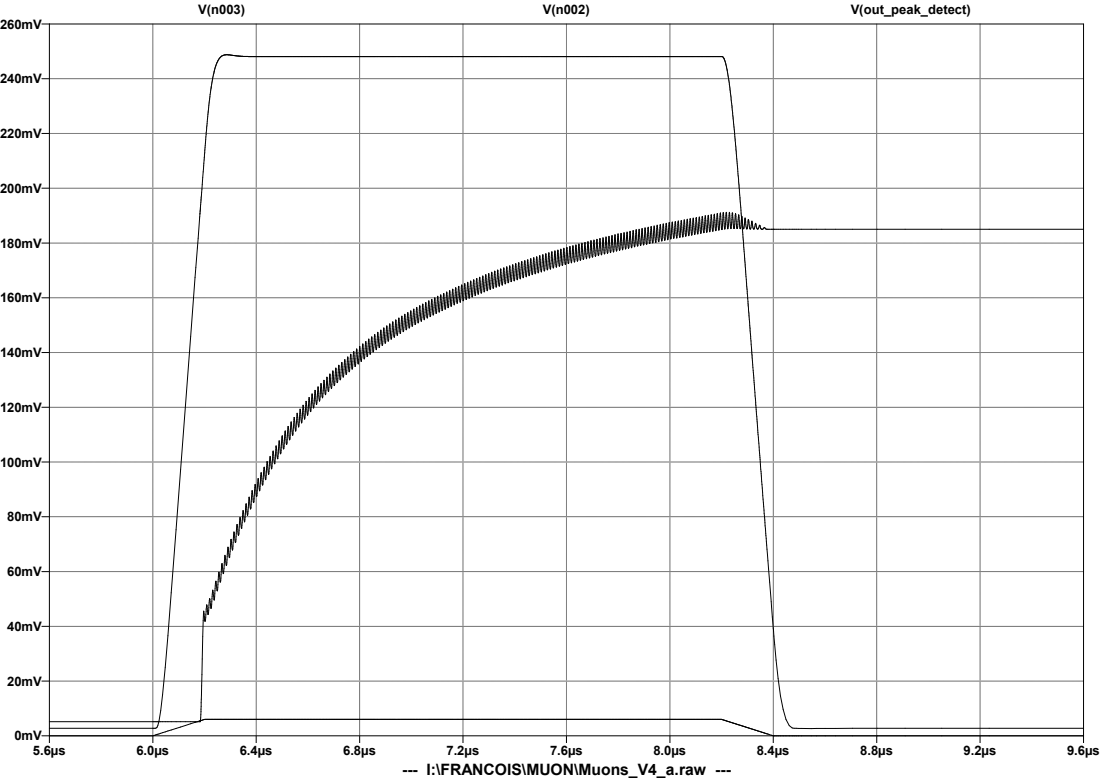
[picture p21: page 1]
V(out_peak_detect)

--- I:\FRANCOIS\MUON\Muons_V4_a.raw ---

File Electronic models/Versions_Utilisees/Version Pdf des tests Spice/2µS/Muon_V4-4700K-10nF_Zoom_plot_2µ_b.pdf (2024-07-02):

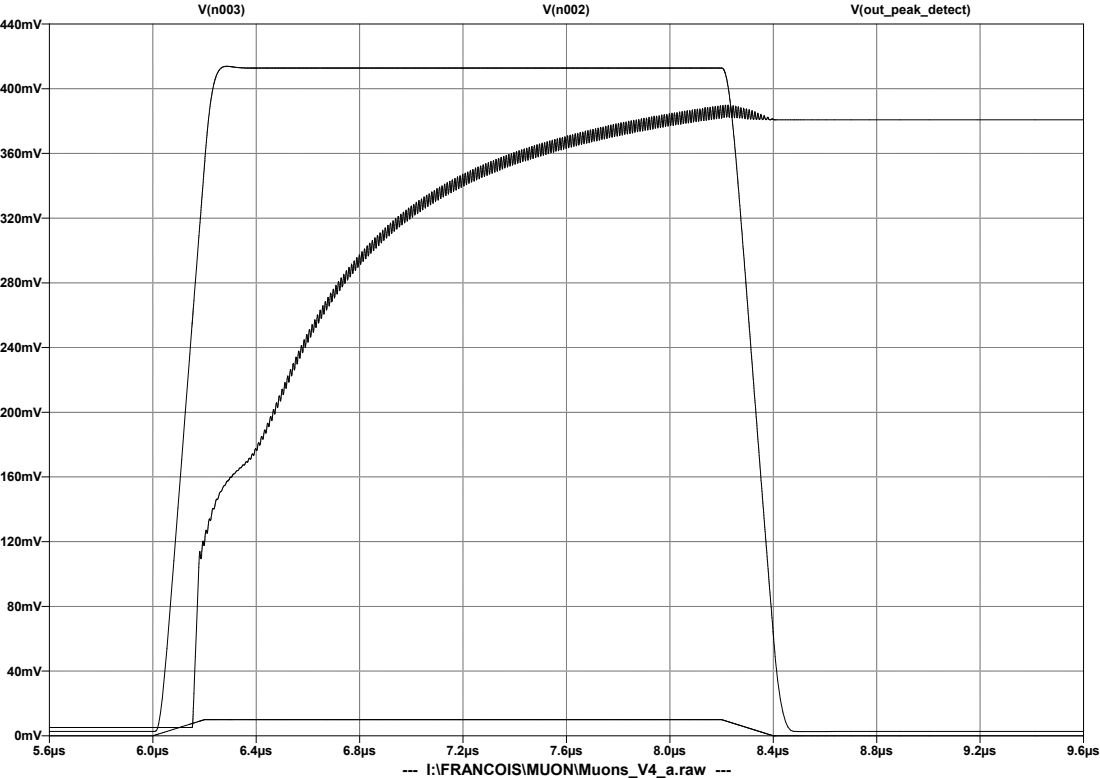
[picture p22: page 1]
V(out_peak_detect)

--- I:\FRANCOIS\MUON\Muons_V4_a.raw ---

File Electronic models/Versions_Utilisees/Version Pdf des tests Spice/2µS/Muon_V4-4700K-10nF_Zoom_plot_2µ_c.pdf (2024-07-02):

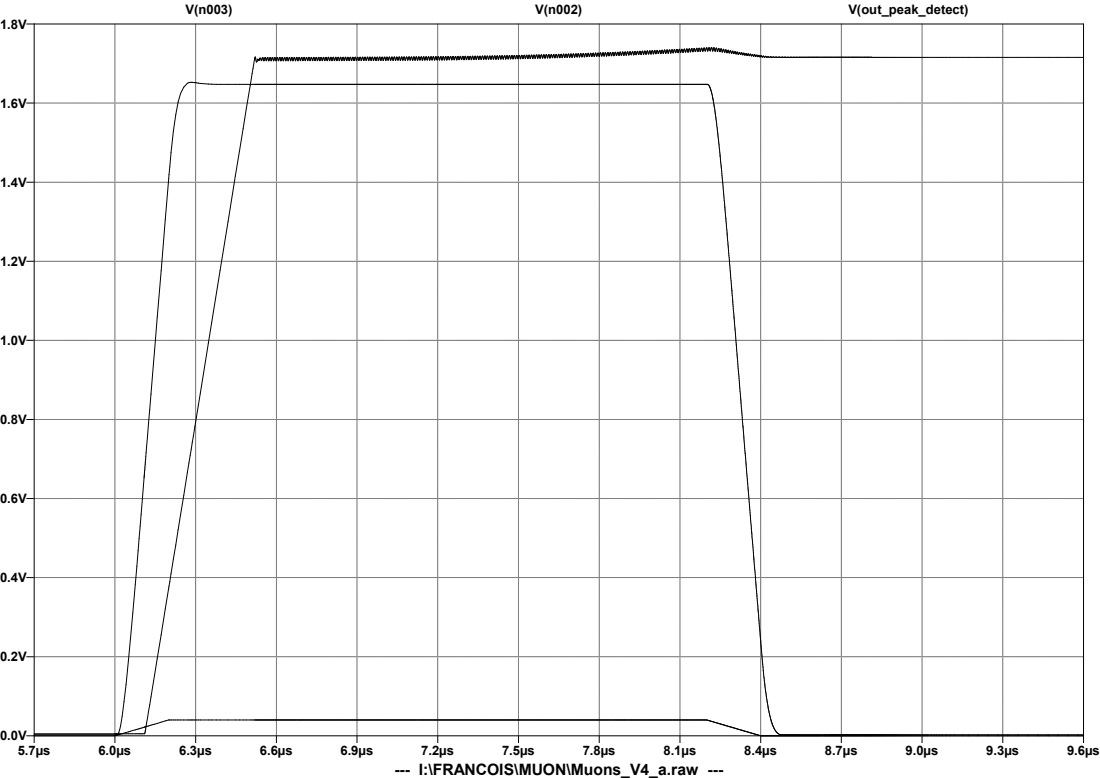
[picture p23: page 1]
V(out_peak_detect)

--- I:\FRANCOIS\MUON\Muons_V4_a.raw ---

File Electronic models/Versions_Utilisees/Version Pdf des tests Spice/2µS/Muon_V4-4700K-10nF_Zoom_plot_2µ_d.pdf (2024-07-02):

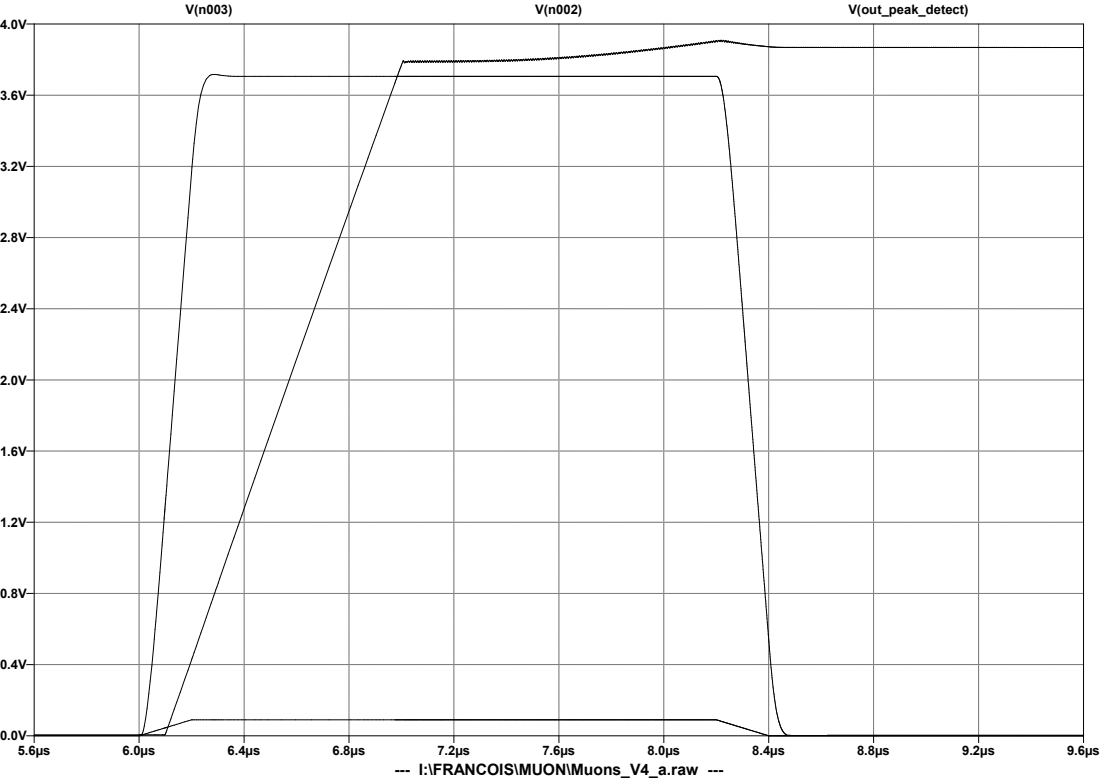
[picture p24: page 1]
V(out_peak_detect)

--- I:\FRANCOIS\MUON\Muons_V4_a.raw ---

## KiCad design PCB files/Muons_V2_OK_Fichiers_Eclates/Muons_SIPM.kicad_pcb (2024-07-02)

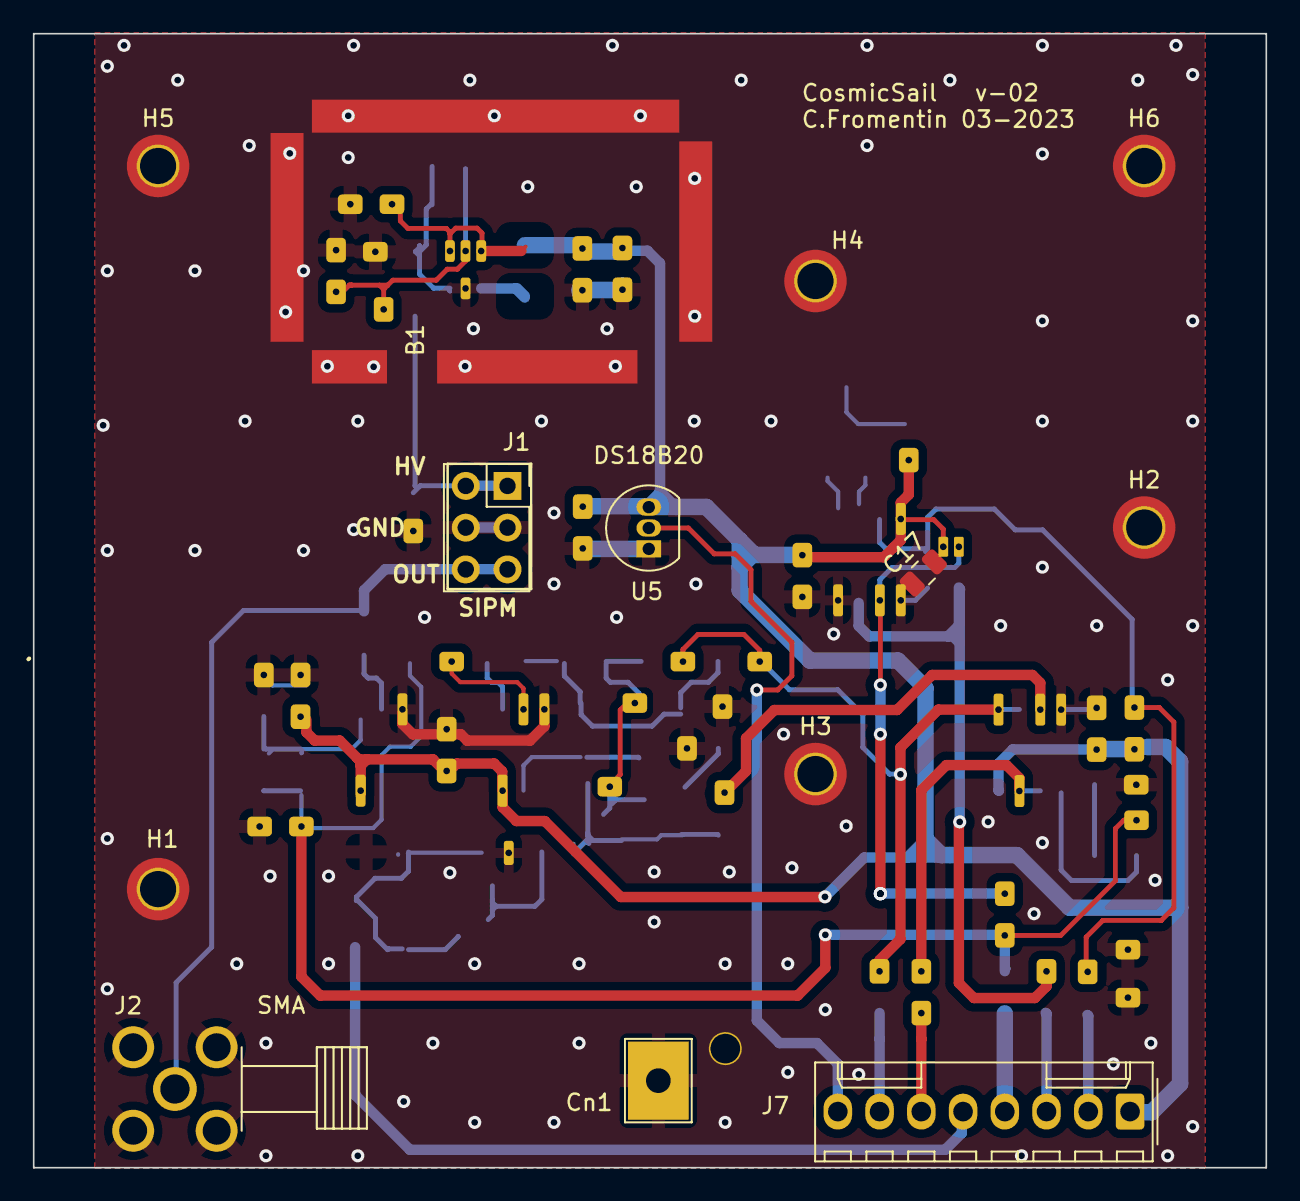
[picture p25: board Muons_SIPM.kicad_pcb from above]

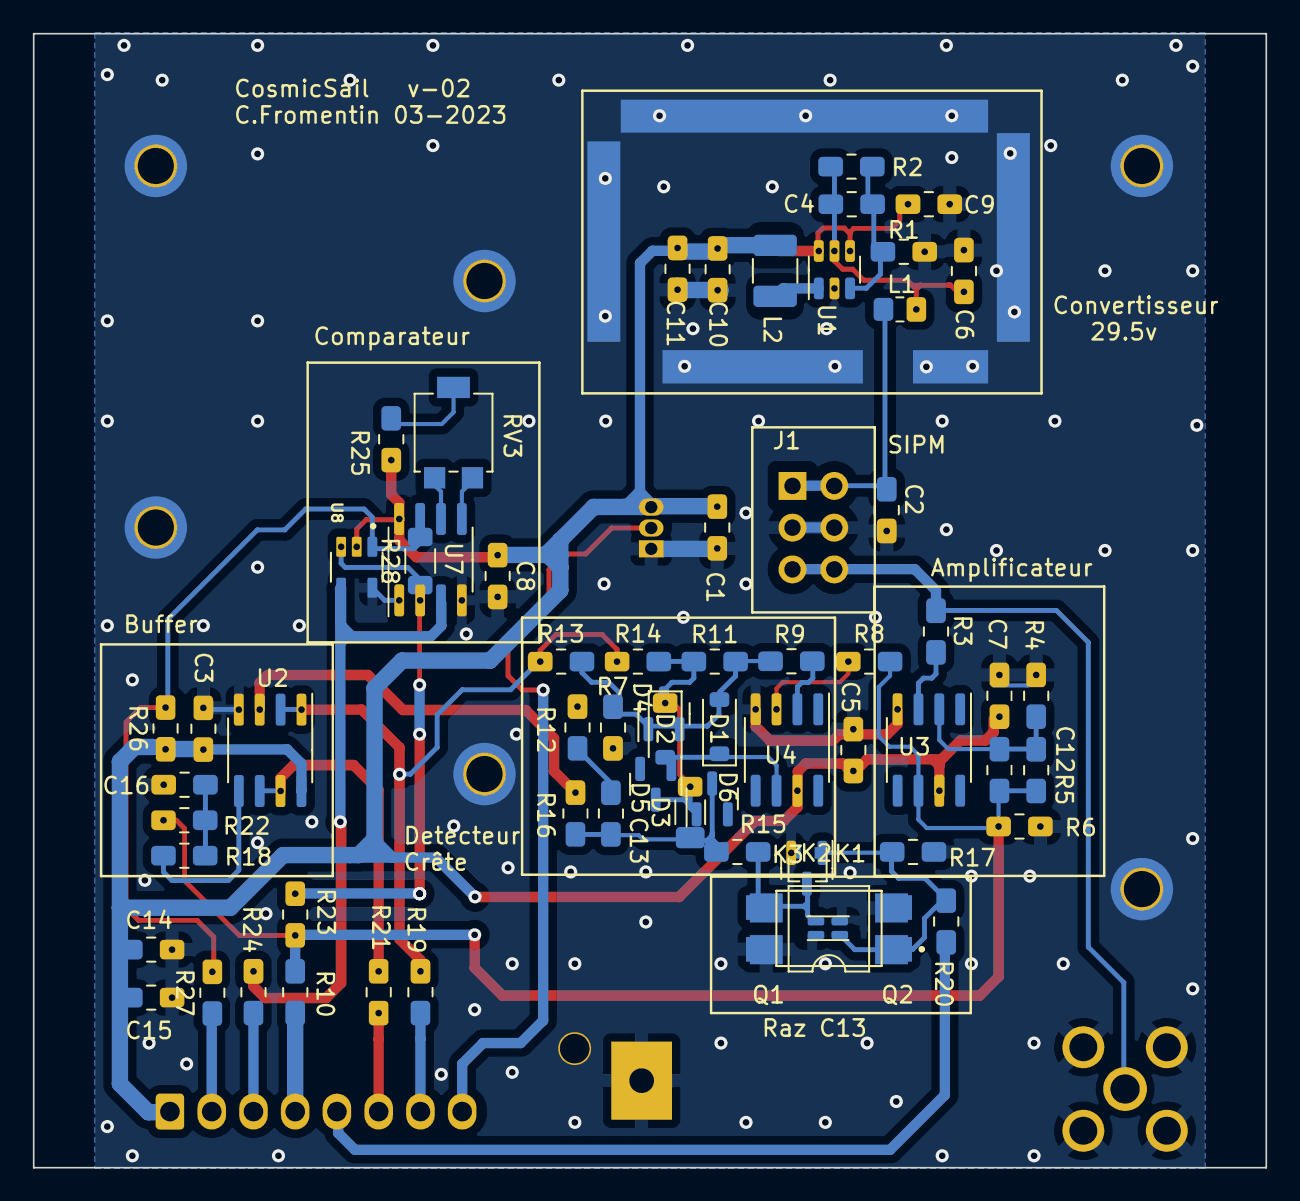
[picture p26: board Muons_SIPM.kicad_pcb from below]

Board: 2 copper layers, 75.0 x 69.0 mm, 77 parts (64 on the bottom side), 37 nets.

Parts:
B1: Blindage; Blindage_29.5
C1, C3, C5, C7, C8, C11, C14: 0.1µF; C_0805_Muons
C2, C9: 1µF; C_0805_Muons
C4: 22pF; C_0805_Muons
C6: 0.47µF; C_0805_Muons
C10, C15: 10µF; C_0805_Muons
C12: 10pF; C_0805_Muons
C13: 4.7nF; C_0805_Muons
C16: 100nF; C_0805_Muons
C17: C_0805_2012Metric
Cn1: GND; TestPoint_THTPad_4.75x3.7mm_Drill1.5mm
D1, D2: D_Schottky; D_SOD-123
D3: D_Schottky; R_1206_3216Metric_Pad1.30x1.75mm_HandSolder
D4, D5, D6: MDB301; SOT-23
H1, H2: SiMP; MountingHole_2.2mm_M2_DIN965_Pad_TopBottom
H3, H4, H5, H6: Board_SiMP; MountingHole_2.2mm_M2_DIN965_Pad_TopBottom
J1: WM17457-ND; PinSocket_2x03_P2.54mm_Vertical
J2: 221790-1; TE_221790-1
J7: Conn_01x08_Socket; Molex_KK-254_AE-6410-08A_1x08_P2.54mm_Vertical
K1: G3VM-21GR1
K2: G3VM-41DY; RELAY_G3VM-41DY
K3: G3VM-81UR
L1: Ferrite Bead; R_0805_2012Metric_Pad1.20x1.40mm_HandSolder
L2: 47µH; R_1210_3225Metric_Pad1.30x2.65mm_HandSolder
Q1: BMBT3904; SOT-323_SC-70
Q2: BSS138; SOT-23
R1, R6, R13, R14, R16, R17, R18: 10k; R_0805_Muons
R2: 226k; R_0805_Muons
R3, R4, R8, R9, R12, R15, R23, R24, R26: 1k; R_0805_Muons
R5: 7.5k; R_0805_Muons
R7, R22: 100k; R_0805_Muons
R10, R19, R20, R21, R27: 470; R_0805_Muons
R11: 4.7M; R_0805_Muons
R25: 3.3k; R_0805_Muons
R28: R_1206_3216Metric
RV3: 5k; Potentiometer_Bourns_3314G_Vertical
U1: LT3461; TSOT-23-6
U2: AD823A; SOIC-8_3.9x4.9mm_P1.27mm
U3, U4: LT1806; SOIC-8_3.9x4.9mm_P1.27mm
U5: DS18B20; TO-92_Inline
U7: LM311; SOIC-8_3.9x4.9mm_P1.27mm
U8: MAX988EUK+; SOT95P280X145-5N

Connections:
/S_5V: C1.1, C3.1, C5.1, C7.1, C8.1, C9.1, C10.1, C11.1, C14.1, C15.1, J7.1, L2.2, R25.1, R26.1, U1.4 (CTRL), U1.6 (VIN), U2.8 (V+), U3.7 (V+), U4.7 (V+), U5.3 (V_{DD}), U7.8 (V+), U8.2 (VCC)
/S_COMPAR: J7.2, R27.1
/S_OUT Dac_Filtre: J7.3, R24.2
/S_Out Amp: J7.4, R10.2
/S_Out Amp Filtre: J7.6, R21.1
/S_Out Detect: J7.7, R19.1
/S_Out T° DS18: J7.8, U5.2 (DQ)
/S_RAZ Condo: J7.5, R20.1
GND: B1.1 (GND), C1.2, C2.2, C3.2, C5.2, C6.2, C7.2, C8.2, C9.2, C10.2, C11.2, C14.2, C15.2, C16.2, Cn1.1, H1.1, H2.1, H3.1, H4.1, H5.1, H6.1, J1.3, J1.4, J2.2, J2.3, J2.4, J2.5, K1.2, K1.4, K2.2, K2.4, K3.2, K3.4, Q1.2 (E), Q2.2 (S), R1.1, R4.1, R6.1, R7.1, R12.1, R17.2, U1.2 (GND), U2.4 (V-), U3.4 (V-), U4.4 (V-), U5.1 (GND), U7.1 (GND), U7.4 (V-), U8.5 (VEE)
unnamed: C12.2, R5.2, R6.2, R8.2, R10.1, R22.2, R23.2, U3.6
unnamed: C13.2, R12.2
unnamed: C16.1, R18.2, R22.1
unnamed: D1.2 (A), D4.1 (A), R7.2, R9.2, R11.1, R13.2
unnamed: D1.1 (K), D2.2 (A), D4.3 (K), D5.1 (A), U4.6
unnamed: D2.1 (K), D3.2 (A), D5.3 (K), D6.1 (A), R11.2, R14.2
unnamed: C13.1, D3.1 (K), D6.3 (K), R15.2, R16.2
unnamed: C2.1, J1.1, J1.2, L1.1
unnamed: J1.5, J1.6, J2.1, R3.1
unnamed: K1.1, K2.1, K3.1, Q1.1 (B), Q2.1 (G), R17.1, R20.2
unnamed: K1.3, K2.3, K3.3, Q1.3 (C), Q2.3 (D), R15.1
unnamed: R25.2, RV3.2
unnamed: C4.1, R1.2, R2.1, U1.3 (FB)
unnamed: L2.1, U1.1 (SW)
unnamed: C4.2, C6.1, L1.2, R2.2, U1.5 (VOUT)
unnamed: R16.1, U2.3 (+)
unnamed: R13.1, R14.1, R19.2, U2.1, U2.2 (-)
unnamed: R18.1, U2.5 (+)
unnamed: R21.2, U2.6 (-), U2.7
unnamed: R3.2, U3.3 (+)
unnamed: C12.1, R4.2, R5.1, U3.2 (-)
unnamed: R8.1, U4.3 (+)
unnamed: R9.1, U4.2 (-)
unnamed: R23.1, U7.2 (+), U8.3 (IN+)
unnamed: R24.1, U7.3 (-), U8.4 (IN-)
unnamed: RV3.3, U7.5 (BAL)
unnamed: RV3.1, U7.6 (STRB)
unnamed: R26.2, R27.2, U7.7, U8.1 (OUT)

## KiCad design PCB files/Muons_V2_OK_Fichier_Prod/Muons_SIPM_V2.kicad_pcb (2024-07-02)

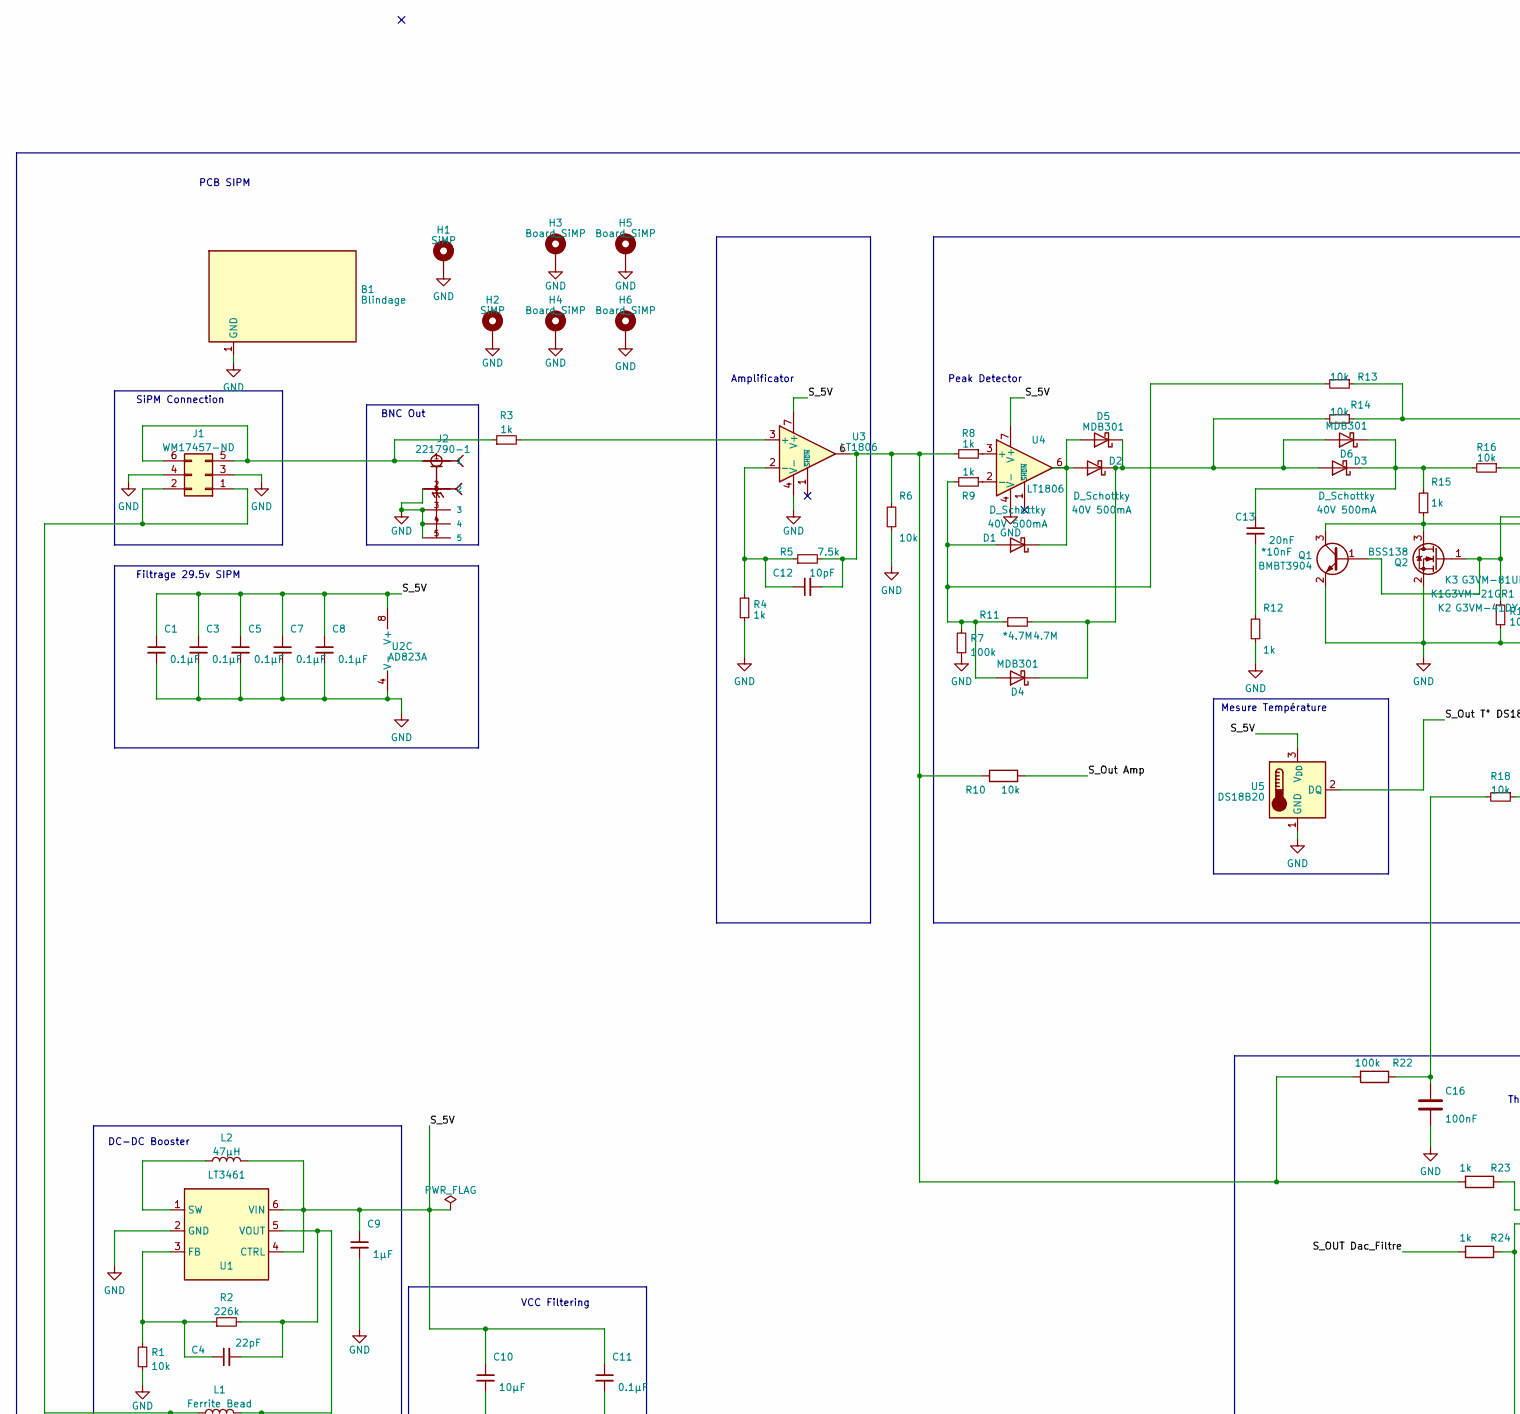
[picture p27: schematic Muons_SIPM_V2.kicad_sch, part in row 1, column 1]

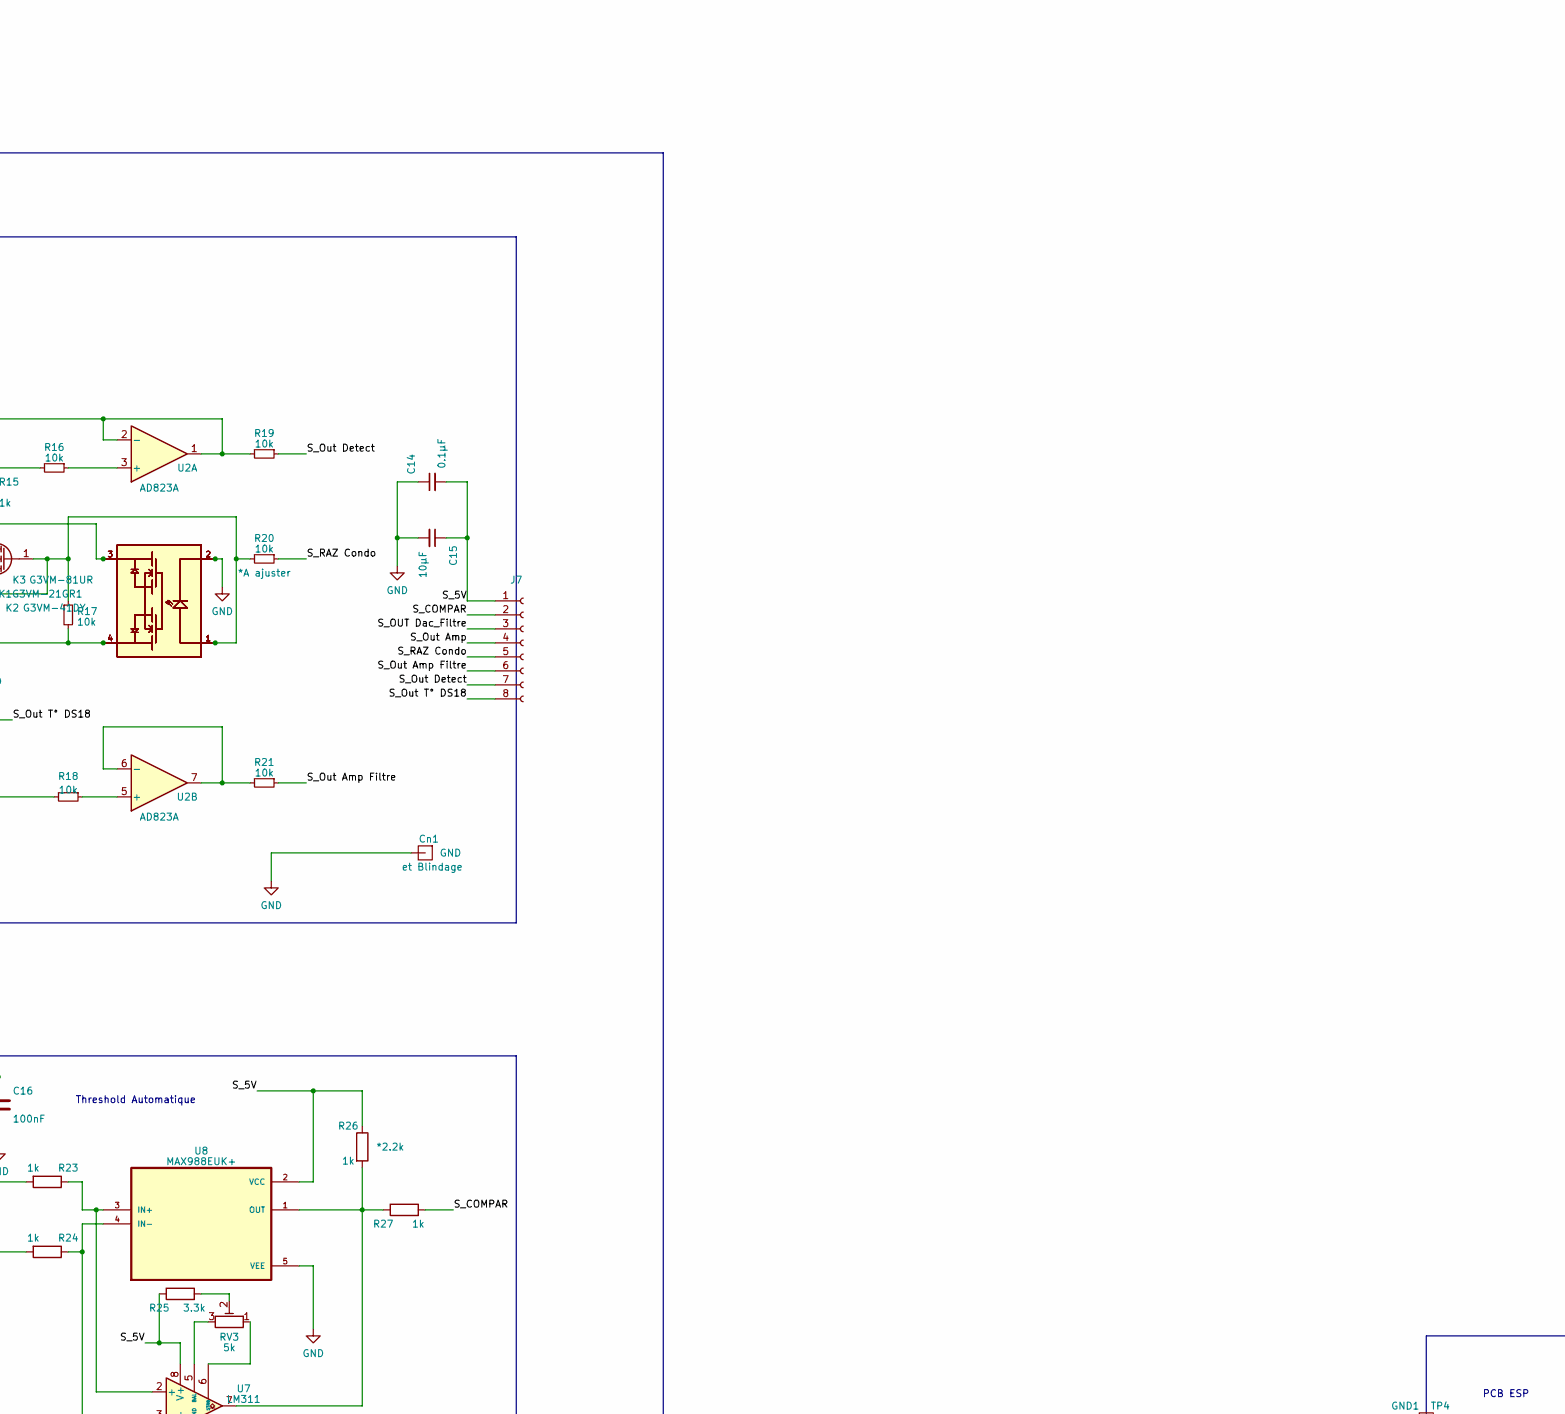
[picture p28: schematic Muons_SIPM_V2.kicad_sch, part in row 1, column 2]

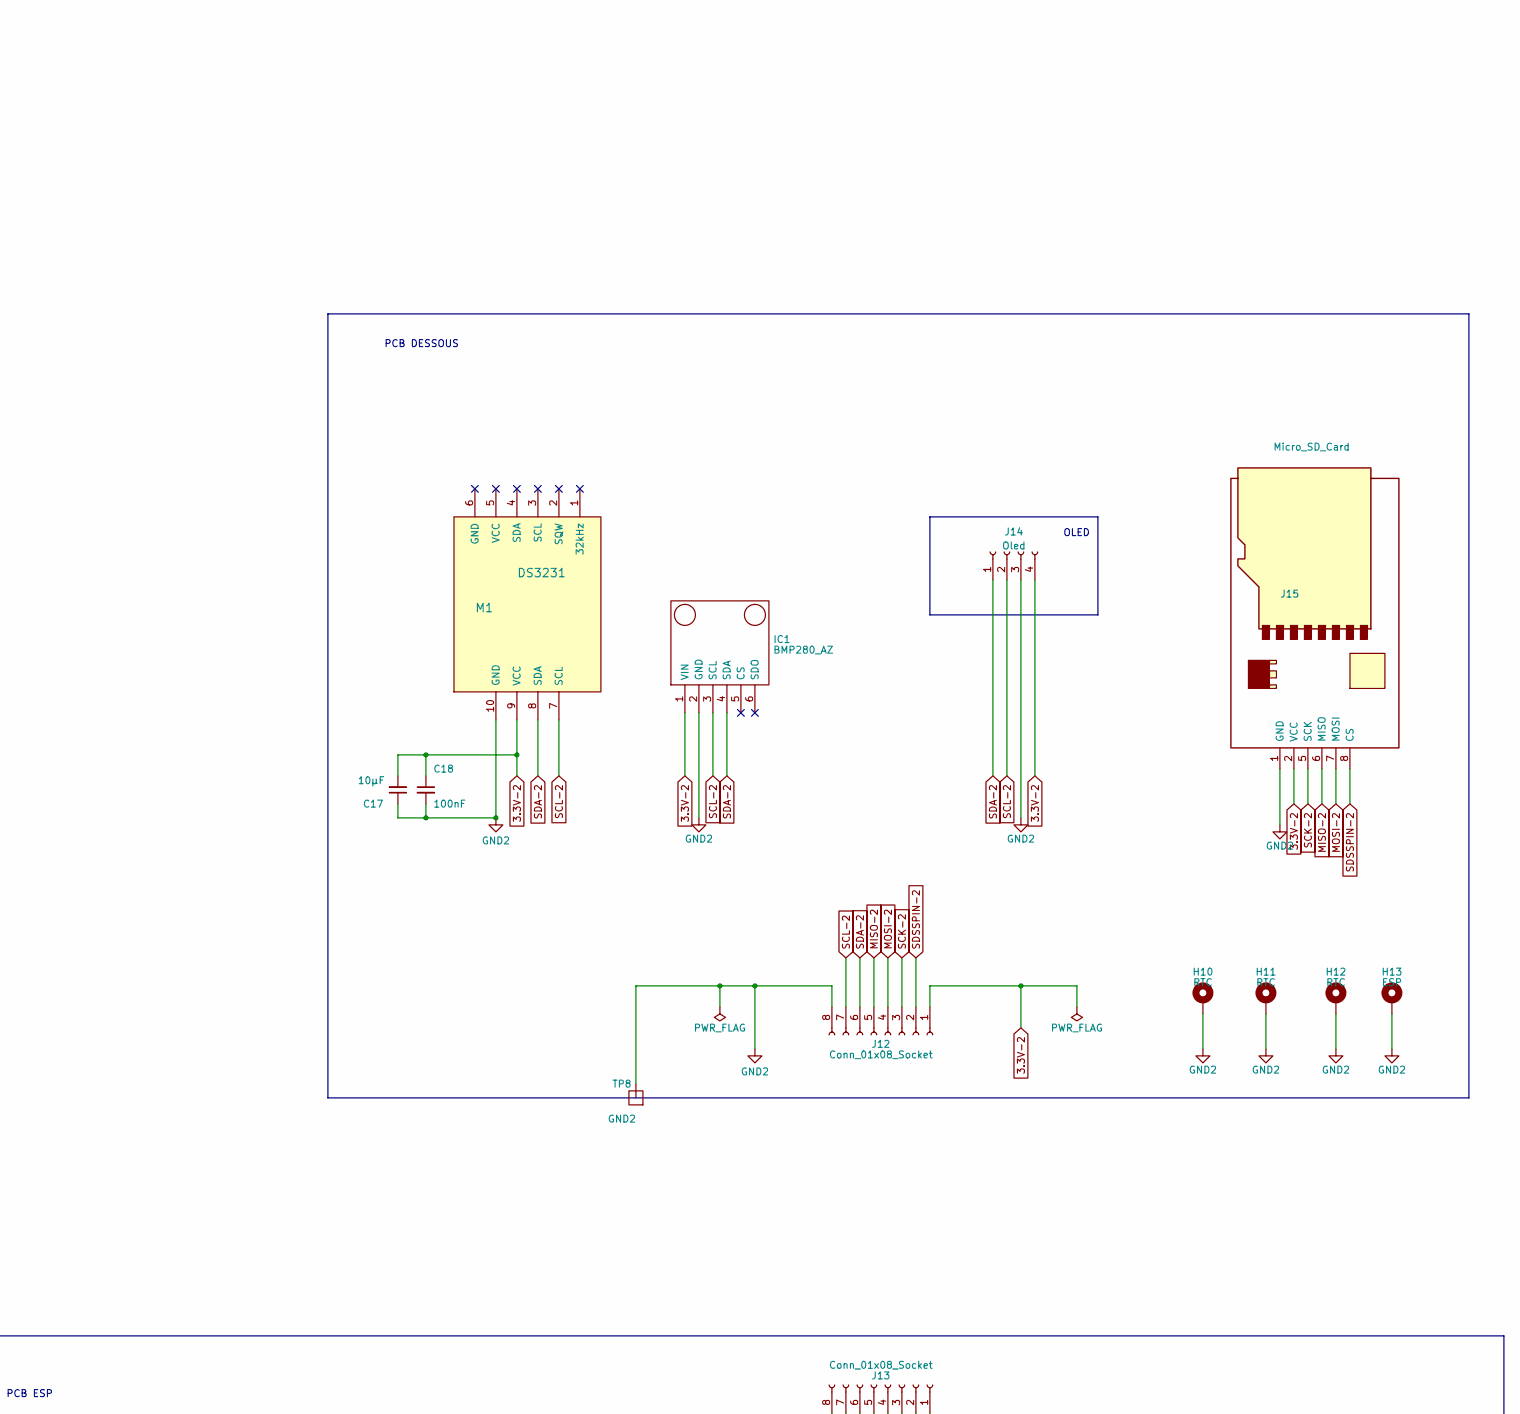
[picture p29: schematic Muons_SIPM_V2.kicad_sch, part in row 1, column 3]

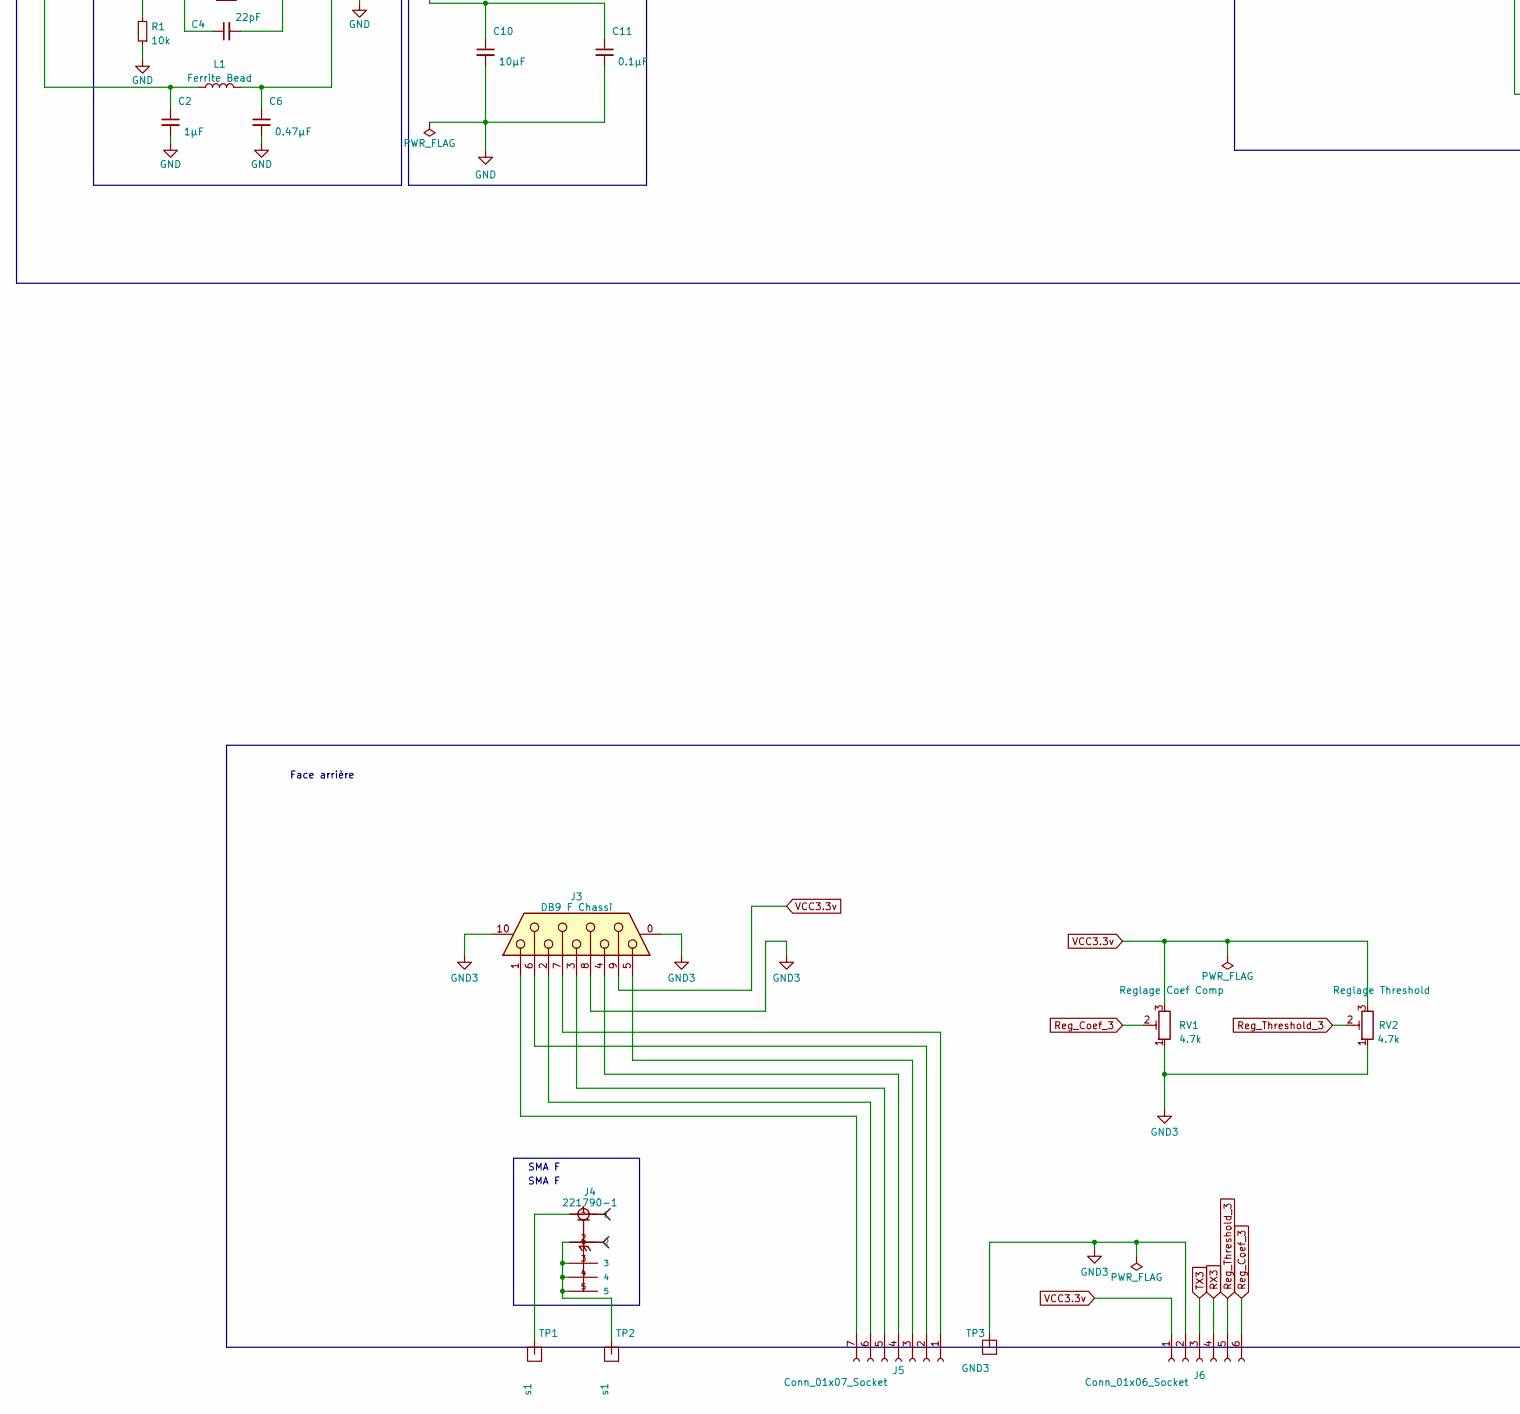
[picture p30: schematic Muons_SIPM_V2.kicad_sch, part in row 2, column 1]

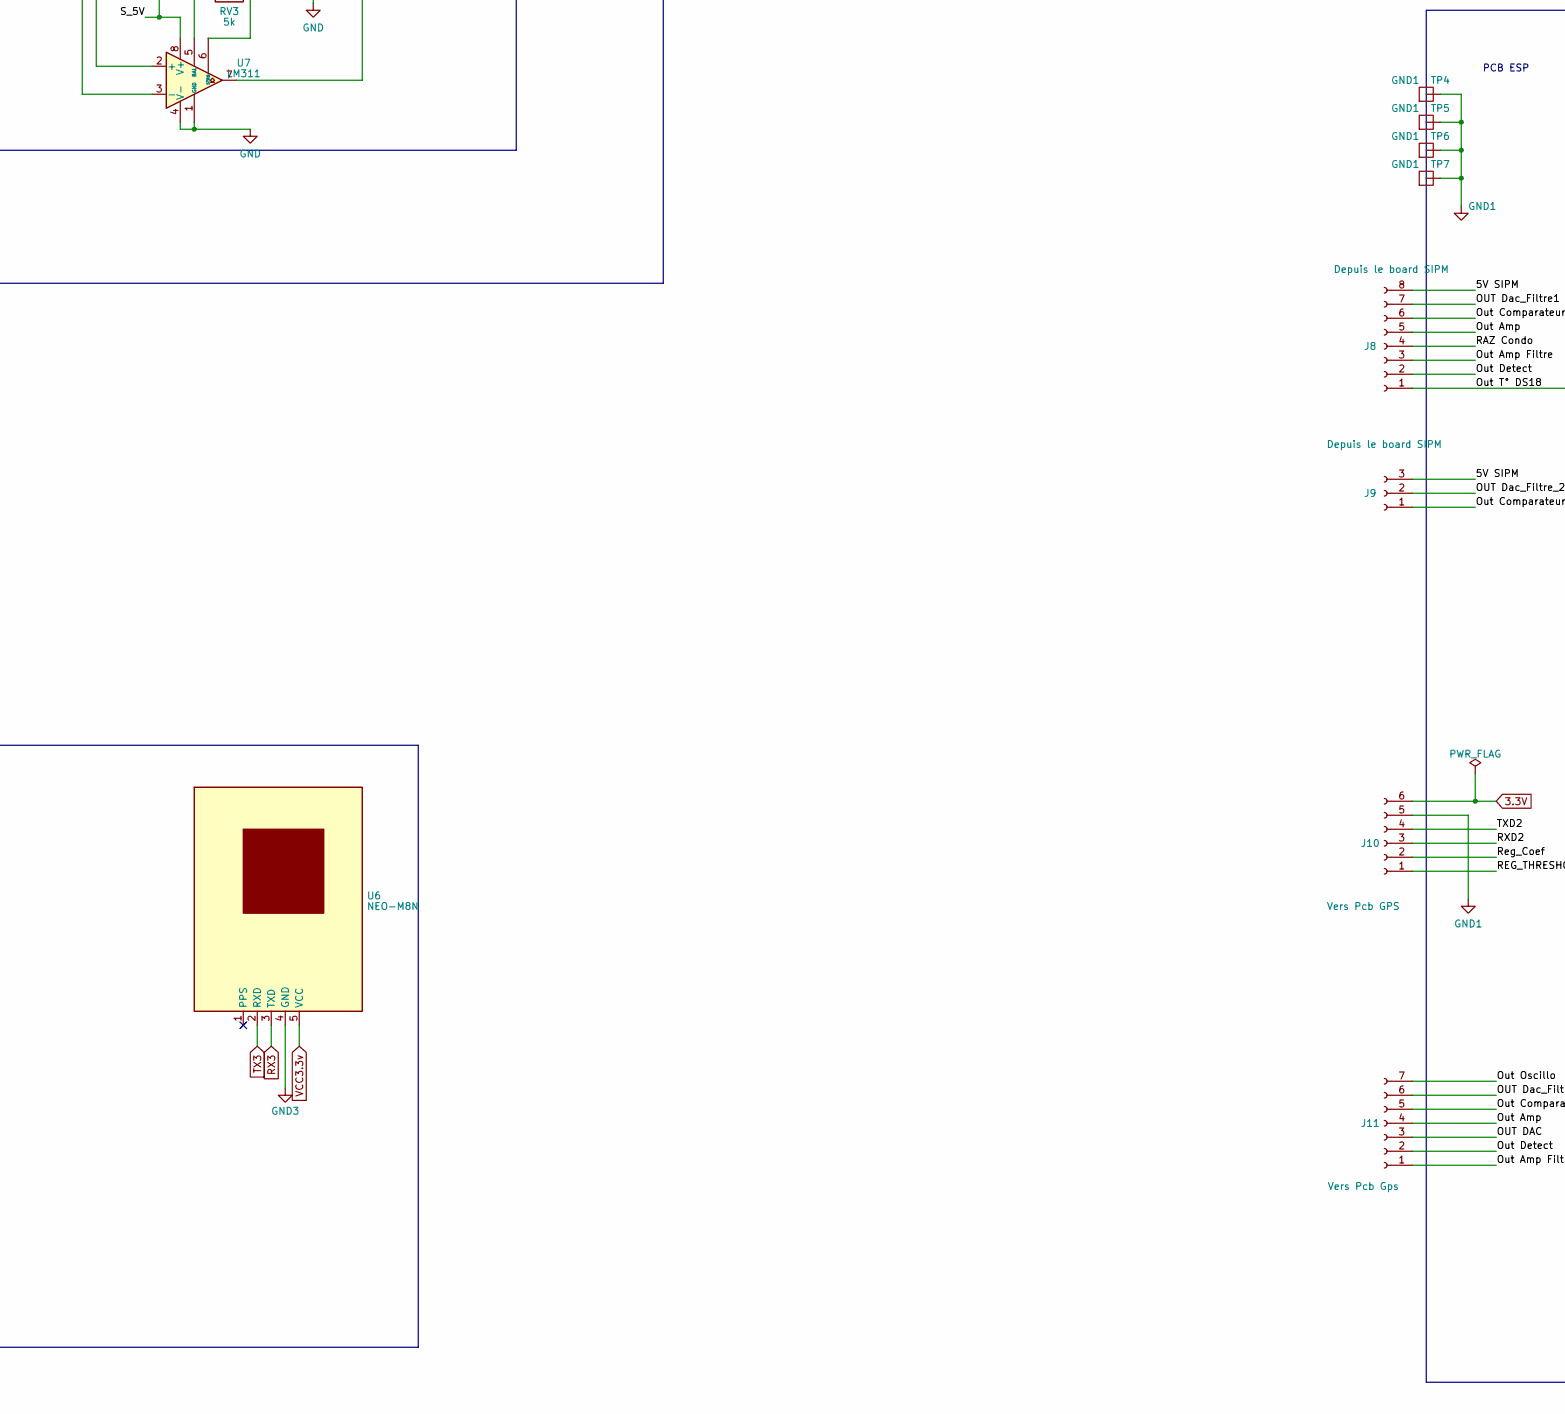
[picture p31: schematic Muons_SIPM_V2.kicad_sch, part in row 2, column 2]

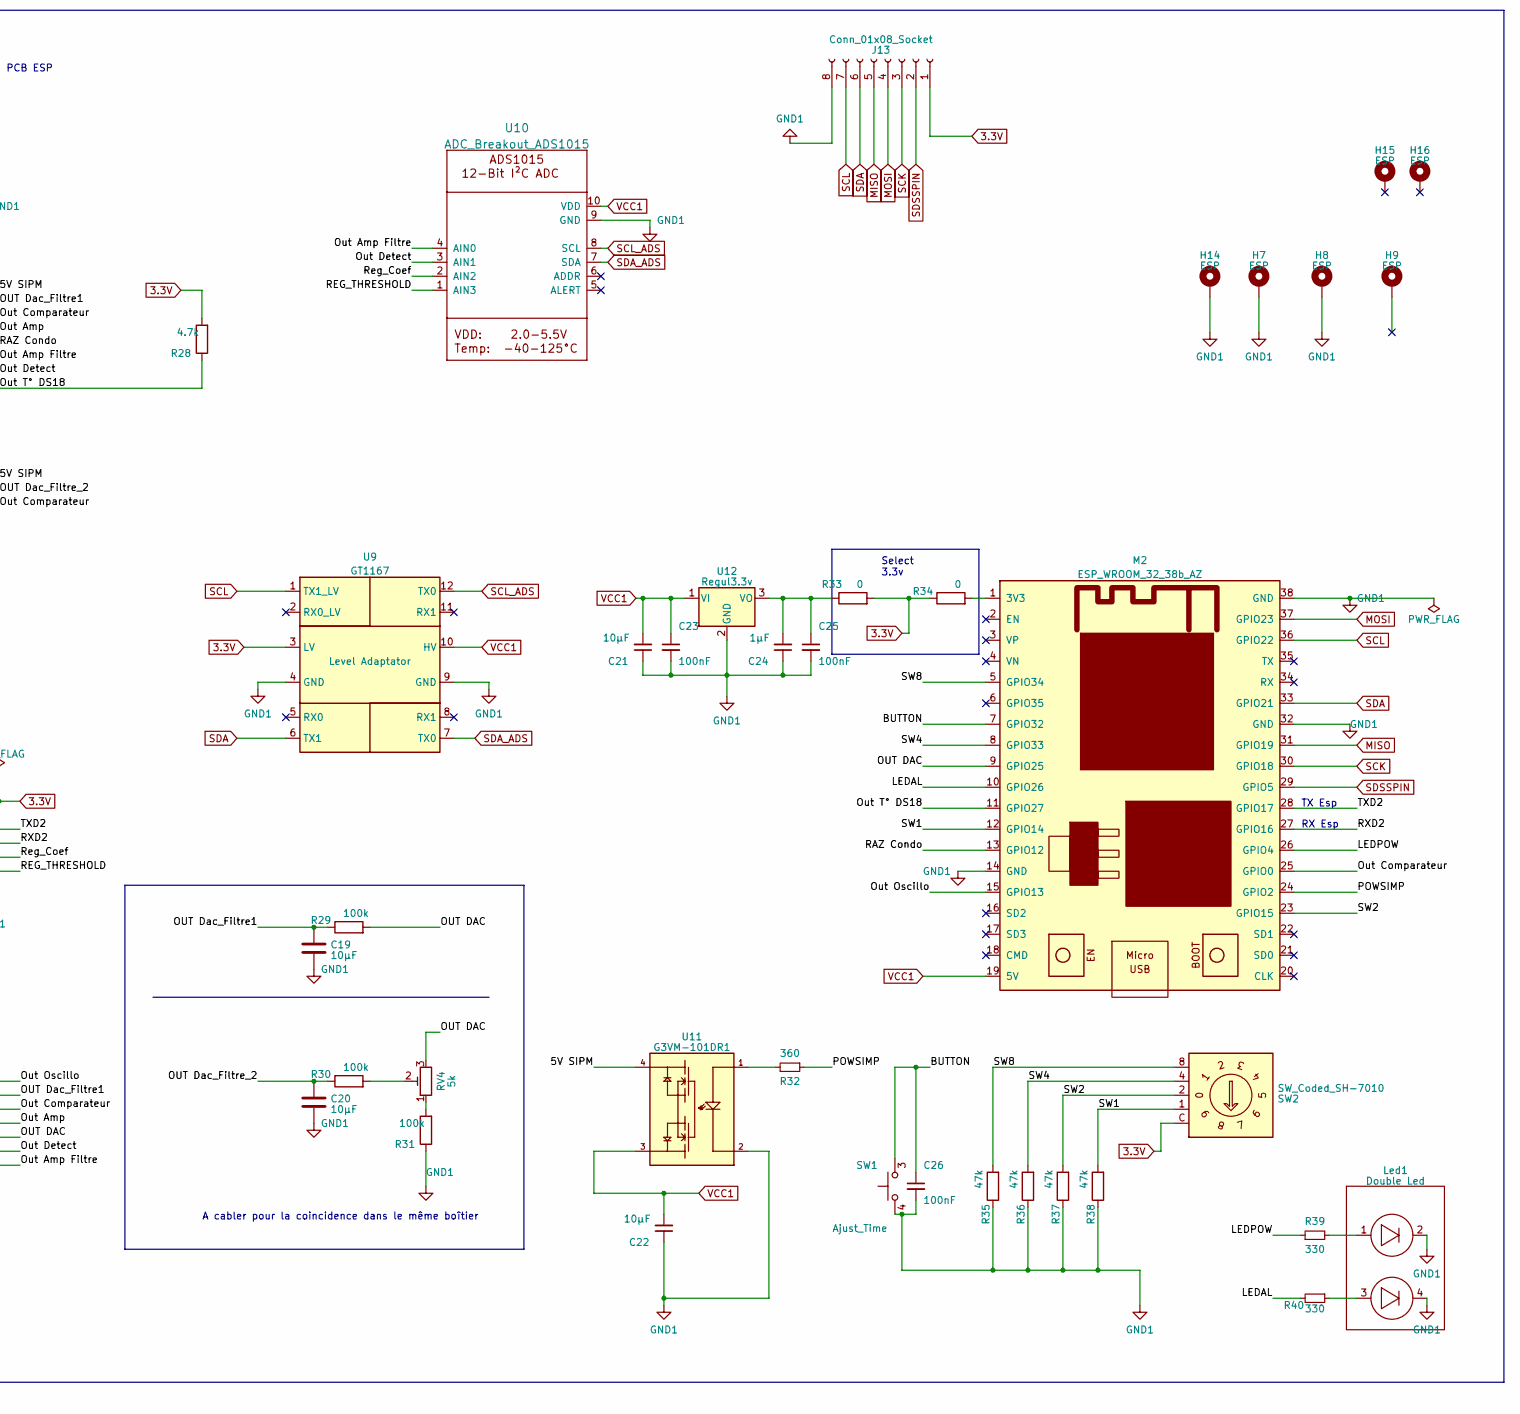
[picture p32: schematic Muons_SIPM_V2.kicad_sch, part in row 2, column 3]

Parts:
B1: Blindage; Blindage_29.5
C1, C3, C5, C7, C8, C11, C14: 0.1µF; C_0805_Muons
C2, C9, C24: 1µF; C_0805_Muons
C4: 22pF; C_0805_Muons
C6: 0.47µF; C_0805_Muons
C10, C15, C17, C19, C20, C21, C22: 10µF; C_0805_Muons
C12: 10pF; C_0805_Muons
C13: 20nF; C_0805_Muons
C16, C18, C23, C25, C26: 100nF; C_0805_Muons
Cn1: GND; TestPoint_THTPad_4.75x3.7mm_Drill1.5mm
D1, D2, D3: D_Schottky; D_SOD-123
D4, D5, D6: MDB301; SOT-23
H1, H2: SiMP; MountingHole_2.2mm_M2_DIN965_Pad_TopBottom
H3, H4, H5, H6: Board_SiMP; MountingHole_2.2mm_M2_DIN965_Pad_TopBottom
H7, H8, H9, H13, H14: ESP; MountingHole_2.2mm_M2_DIN965_Pad_TopBottom
H10, H11, H12: RTC; MountingHole_2.2mm_M2_DIN965_Pad_TopBottom
H15, H16: ESP; MountingHole_2.2mm_M2
IC1: BMP280_AZ; Manufacturer_Part_Number BMP280_AZ
J1: WM17457-ND; PinSocket_2x03_P2.54mm_Vertical
J2, J4: 221790-1; TE_221790-1
J3: DB9 F Chassi; DSUB-9_Female_Horizontal_P2.77x2.84mm_EdgePinOffset4.94mm_H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
J5: Conn_01x07_Socket; Molex_KK-254_AE-6410-07A_1x07_P2.54mm_Vertical
J6: Conn_01x06_Socket; Molex_KK-254_AE-6410-06A_1x06_P2.54mm_Vertical
J7: Conn_01x08_Socket; Molex_KK-254_AE-6410-08A_1x08_P2.54mm_Vertical
J8: Depuis le board SIPM; Molex_KK-254_AE-6410-08A_1x08_P2.54mm_Vertical
J9: Depuis le board SIPM; Molex_KK-254_AE-6410-03A_1x03_P2.54mm_Vertical
J10: Vers Pcb GPS; Molex_KK-254_AE-6410-06A_1x06_P2.54mm_Vertical
J11: Vers Pcb Gps; Molex_KK-254_AE-6410-07A_1x07_P2.54mm_Vertical
J12: Conn_01x08_Socket; PinSocket_1x08_P2.54mm_Vertical
J13: Conn_01x08_Socket; PinHeader_1x08_P2.54mm_Vertical
J14: Oled; OLED_PCB
J15: Micro_SD_Card; SD-CARD_AZ
K1: G3VM-21GR1; PARTREV 0215
K2: G3VM-41DY; RELAY_G3VM-41DY; PARTREV 0215
K3: G3VM-81UR; PARTREV 0215
L1: Ferrite Bead; R_0805_2012Metric_Pad1.20x1.40mm_HandSolder
L2: 47µH; R_1210_3225Metric_Pad1.30x2.65mm_HandSolder
Led1: Double Led; Double_Led
M1: DS3231; REG_DS3231_2023
M2: ESP_WROOM_32_38b_AZ; MODULE_ESP32-DEVKITC
Q1: BMBT3904; SOT-323_SC-70
Q2: BSS138; SOT-23
R1, R6, R10, R13, R14, R16, R17, R18, R19, R20, R21: 10k; R_0805_Muons
R2: 226k; R_0805_Muons
R3, R4, R8, R9, R12, R15, R23, R24, R26, R27: 1k; R_0805_Muons
R5: 7.5k; R_0805_Muons
R7, R22, R29, R30, R31: 100k; R_0805_Muons
R11: 4.7M; R_0805_Muons
R25: 3.3k; R_0805_Muons
R28: 4.7k; R_0805_Muons
R32: 360; R_0805_Muons
R33, R34: 0; R_Shunt_0805_Muons
R35, R36, R37, R38: 47k; R_0805_Muons
R39, R40: 330; R_0805_Muons
RV1, RV2: 4.7k; Potentiometer_Bourns_3005_Horizontal
RV3, RV4: 5k; Potentiometer_Bourns_3314G_Vertical
SW1: Ajust_Time; SW_Tactile_SPST_Angled_PTS645Vx83-2LFS
SW2: SW_Coded_SH-7010; Nidec_Copal_SC-1110
TP1, TP2: s1; TestPoint_THTPad_4.75x3.7mm_Drill1.5mm
TP3: GND3; TestPoint_THTPad_4.75x3.7mm_Drill1.5mm
TP4, TP5, TP6, TP7: GND1; TestPoint_THTPad_4.75x3.7mm_Drill1.5mm
TP8: GND2; TestPoint_THTPad_4.75x3.7mm_Drill1.5mm
U1: LT3461; TSOT-23-6
U2: AD823A; SOIC-8_3.9x4.9mm_P1.27mm
U3, U4: LT1806; SOIC-8_3.9x4.9mm_P1.27mm
U5: DS18B20; TO-92_Inline
U6: NEO-M8N; GPS_NEO8
U7: LM311; SOIC-8_3.9x4.9mm_P1.27mm
U8: MAX988EUK+; SOT95P280X145-5N
U9: GT1167; DIP-12_Convertisseur
U10: ADC_Breakout_ADS1015; ADS1115_Small_BreakBord
U11: G3VM-101DR1; G3VM-21GR1; PARTREV 0215
U12: Regul3.3v; Regulateur

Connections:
3.3V: J10.6, J13.1, R28.2, R33.2, R34.1, SW2.C, U9.3 (LV)
3.3V-2: C17.2, C18.1, IC1.1 (VIN), J12.1, J14.4, J15.2 (VCC), M1.9 (VCC)
/5V SIPM: J8.8, J9.3, U11.4
/BUTTON: C26.1, M2.7 (GPIO32), SW1.3 (B), SW1.4 (B)
/LEDAL: M2.10 (GPIO26), R40.2
/LEDPOW: M2.26 (GPIO4), R39.1
/OUT DAC: J11.3, M2.9 (GPIO25), R29.2, RV4.3
/OUT Dac_Filtre1: C19.1, J8.7, J11.6, R29.1
/OUT Dac_Filtre_2: C20.1, J9.2, R30.1
/Out Amp: J8.5, J11.4
/Out Amp Filtre: J8.3, J11.1, U10.4 (AIN0)
/Out Comparateur: J8.6, J9.1, J11.5, M2.25 (GPIO0)
/Out Detect: J8.2, J11.2, U10.3 (AIN1)
/Out Oscillo: J11.7, M2.15 (GPIO13)
/Out T° DS18: J8.1, M2.11 (GPIO27), R28.1
/POWSIMP: M2.24 (GPIO2), R32.1
/RAZ Condo: J8.4, M2.13 (GPIO12)
/REG_THRESHOLD: J10.1, U10.1 (AIN3)
/RXD2: J10.3, M2.27 (GPIO16)
/Reg_Coef: J10.2, U10.2 (AIN2)
/SW1: M2.12 (GPIO14), R38.2, SW2.1
/SW2: M2.23 (GPIO15), R37.2, SW2.2
/SW4: M2.8 (GPIO33), R36.2, SW2.4
/SW8: M2.5 (GPIO34), R35.2, SW2.8
/S_5V: C1.1, C3.1, C5.1, C7.1, C8.1, C9.1, C10.1, C11.1, C14.2, C15.1, J7.1, L2.2, R25.1, R26.1, U1.4 (CTRL), U1.6 (VIN), U2.8 (V+), U3.7 (V+), U4.7 (V+), U5.3 (V_{DD}), U7.8 (V+), U8.2 (VCC)
/S_COMPAR: J7.2, R27.2
/S_OUT Dac_Filtre: J7.3, R24.2
/S_Out Amp: J7.4, R10.2
/S_Out Amp Filtre: J7.6, R21.1
/S_Out Detect: J7.7, R19.1
/S_Out T° DS18: J7.8, U5.2 (DQ)
/S_RAZ Condo: J7.5, R20.1
/TXD2: J10.4, M2.28 (GPIO17)
GND: B1.1 (GND), C1.2, C2.2, C3.2, C5.2, C6.2, C7.2, C8.2, C9.2, C10.2, C11.2, C14.1, C15.2, C16.2, Cn1.1, H1.1, H2.1, H3.1, H4.1, H5.1, H6.1, J1.3, J1.4, J2.2, J2.3, J2.4, J2.5, K1.2, K1.4, K2.2, K2.4, K3.2, K3.4, Q1.2 (E), Q2.2 (S), R1.1, R4.1, R6.1, R7.1, R12.1, R17.2, U1.2 (GND), U2.4 (V-), U3.4 (V-), U4.4 (V-), U5.1 (GND), U7.1 (GND), U7.4 (V-), U8.5 (VEE)
GND1: C19.2, C20.2, C21.1, C22.1, C23.2, C24.1, C25.2, C26.2, H7.1, H8.1, H14.1, J10.5, J13.8, Led1.2 (K1), Led1.4 (K2), M2.14 (GND), M2.32 (GND), M2.38 (GND), R31.1, R35.1, R36.1, R37.1, R38.1, SW1.1 (A), SW1.2 (A), TP4.1, TP5.1, TP6.1, TP7.1, U9.4 (GND), U9.9 (GND), U10.9 (GND), U11.2, U12.2 (GND)
GND2: C17.1, C18.2, H10.1, H11.1, H12.1, H13.1, IC1.2 (GND), J12.8, J14.3, J15.1 (GND), M1.10 (GND), TP8.1
GND3: J3.0 (PAD), J3.8, J3.10 (PAD), J6.2, RV1.1, RV2.1, TP3.1, U6.4 (GND)
MISO: J13.5, M2.31 (GPIO19)
MISO-2: J12.5, J15.6 (MISO)
MOSI: J13.4, M2.37 (GPIO23)
MOSI-2: J12.4, J15.7 (MOSI)
unnamed: C12.2, R5.2, R6.2, R8.2, R10.1, R22.2, R23.2, U3.6
unnamed: C13.2, R12.2
unnamed: C16.1, R18.2, R22.1
unnamed: D1.2 (A), D4.1 (A), R7.2, R9.2, R11.1, R13.2
unnamed: D1.1 (K), D2.2 (A), D5.1 (A), U4.6
unnamed: D2.1 (K), D3.2 (A), D4.3 (K), D5.3 (K), D6.1 (A), R11.2, R14.2
unnamed: C13.1, D3.1 (K), D6.3 (K), R15.2, R16.2
unnamed: C2.1, J1.1, J1.2, L1.1
unnamed: J1.5, J1.6, J2.1, R3.1
unnamed: J4.1, TP1.1
unnamed: J4.2, J4.3, J4.4, J4.5, TP2.1
unnamed: J3.7, J5.1
unnamed: J3.6, J5.2
unnamed: J3.5, J5.3
unnamed: J3.4, J5.4
unnamed: J3.3, J5.5
unnamed: J3.2, J5.6
unnamed: J3.1, J5.7
unnamed: Led1.1 (A1), R39.2
unnamed: Led1.3 (A2), R40.1
unnamed: M2.1 (3V3), R34.2
unnamed: K1.1, K2.1, K3.1, Q1.1 (B), Q2.1 (G), R17.1, R20.2
unnamed: K1.3, K2.3, K3.3, Q1.3 (C), Q2.3 (D), R15.1
unnamed: R25.2, RV3.2
unnamed: R30.2, RV4.2
unnamed: R31.2, RV4.1
unnamed: R32.2, U11.1
unnamed: C4.1, R1.2, R2.1, U1.3 (FB)
unnamed: L2.1, U1.1 (SW)
unnamed: C4.2, C6.1, L1.2, R2.2, U1.5 (VOUT)
unnamed: R16.1, U2.3 (+)
unnamed: R13.1, R14.1, R19.2, U2.1, U2.2 (-)
unnamed: R18.1, U2.5 (+)
unnamed: R21.2, U2.6 (-), U2.7
unnamed: R3.2, U3.3 (+)
unnamed: C12.1, R4.2, R5.1, U3.2 (-)
unnamed: R8.1, U4.3 (+)
unnamed: R9.1, U4.2 (-)
unnamed: R23.1, U7.2 (+), U8.3 (IN+)
unnamed: R24.1, U7.3 (-), U8.4 (IN-)
unnamed: RV3.3, U7.5 (BAL)
unnamed: RV3.1, U7.6 (STRB)
unnamed: R26.2, R27.1, U7.7, U8.1 (OUT)
unnamed: C24.2, C25.1, R33.1, U12.3 (VO)
RX3: J6.4, U6.3 (TXD)
Reg_Coef_3: J6.6, RV1.2
Reg_Threshold_3: J6.5, RV2.2
SCK: J13.3, M2.30 (GPIO18)
SCK-2: J12.3, J15.5 (SCK)
SCL: J13.7, M2.36 (GPIO22), U9.1 (TX1_LV)
SCL-2: IC1.3 (SCL), J12.7, J14.2, M1.7 (SCL)
SCL_ADS: U9.12 (TX0), U10.8 (SCL)
SDA: J13.6, M2.33 (GPIO21), U9.6 (TX1)
SDA-2: IC1.4 (SDA), J12.6, J14.1, M1.8 (SDA)
SDA_ADS: U9.7 (TX0), U10.7 (SDA)
SDSSPIN: J13.2, M2.29 (GPIO5)
SDSSPIN-2: J12.2, J15.8 (CS)
TX3: J6.3, U6.2 (RXD)
VCC1: C21.2, C22.2, C23.1, M2.19 (5V), U9.10 (HV), U10.10 (VDD), U11.3, U12.1 (VI)
VCC3.3v: J3.9, J6.1, RV1.3, RV2.3, U6.5 (VCC)

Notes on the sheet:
VCC Filtering
Face arrière
Peak Detector
OLED
PCB DESSOUS
Select 3.3v
PCB ESP
A cabler pour la coincidence dans le même boîtier
PCB SIPM
Mesure Température
RX Esp
SMA F
Filtrage 29.5v SIPM
TX Esp
SiPM Connection
DC-DC Booster
Amplificator
Threshold Automatique
BNC Out

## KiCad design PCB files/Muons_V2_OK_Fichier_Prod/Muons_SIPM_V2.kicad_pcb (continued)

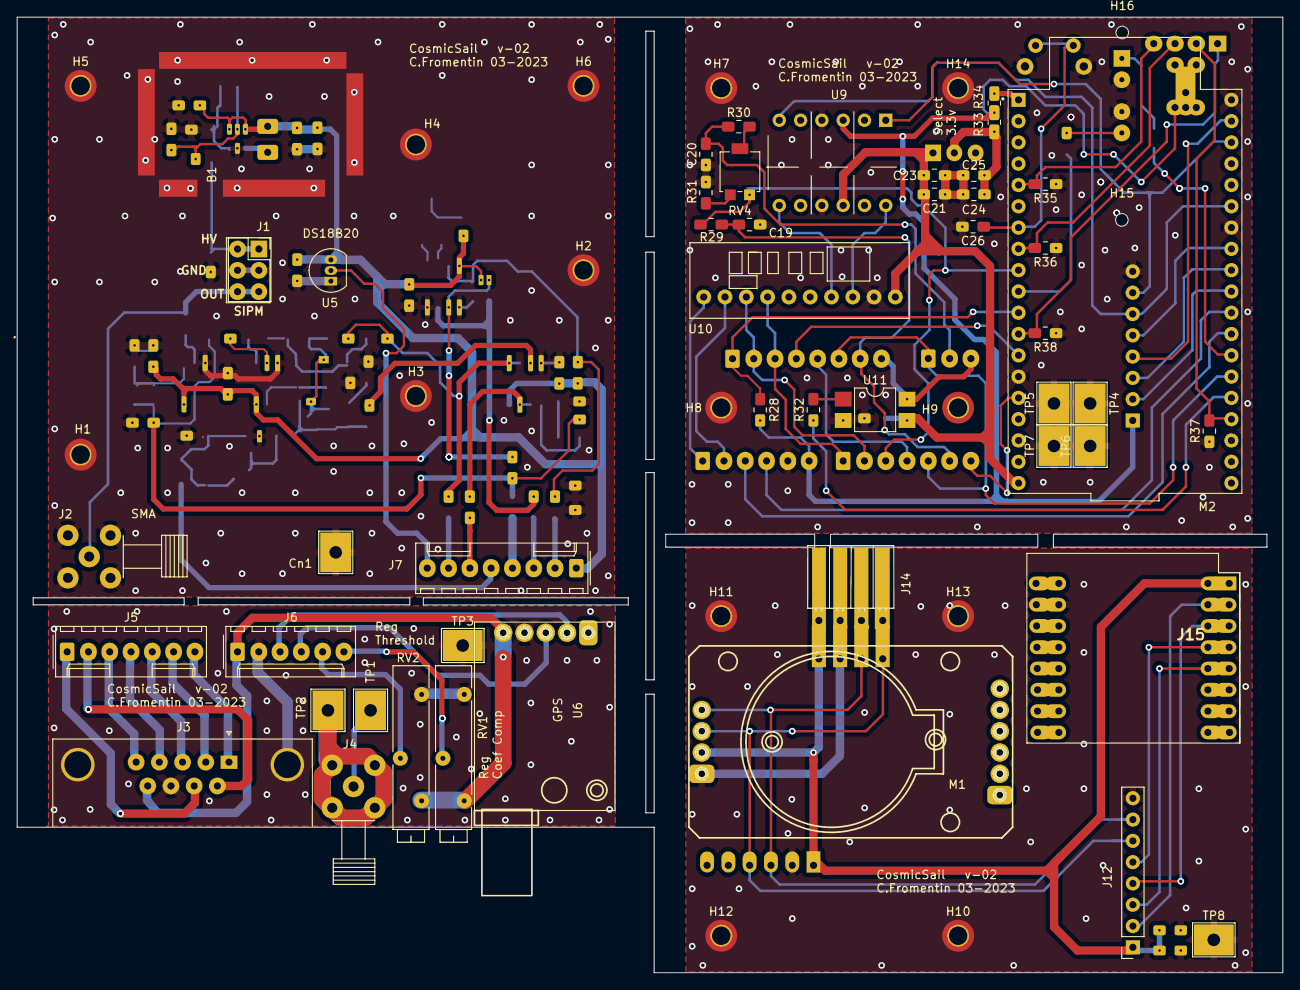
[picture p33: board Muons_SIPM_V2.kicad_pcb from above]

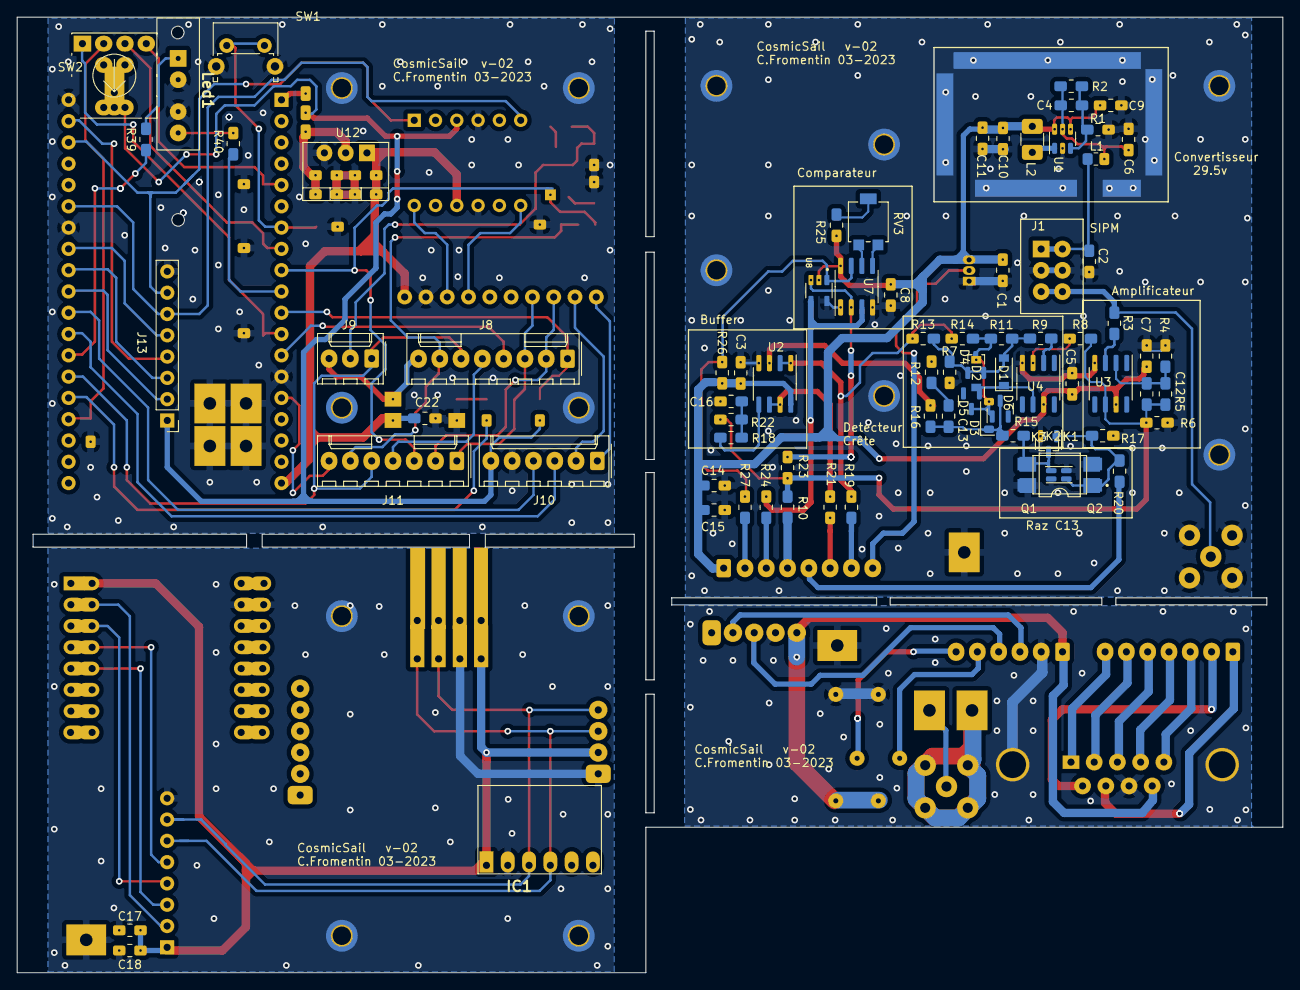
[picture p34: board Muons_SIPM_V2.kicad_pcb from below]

Board: 2 copper layers, 151.0 x 114.0 mm, 142 parts (78 on the bottom side), 101 nets.

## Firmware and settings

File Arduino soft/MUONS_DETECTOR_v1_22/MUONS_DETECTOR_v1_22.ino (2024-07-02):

#include <Arduino.h>
/*  CosmicSail - Muon detector   Release 1.221  (CF : relnum below)                           
  Last modification by YLC on May 253, 2023 (Reading the voltage sent by the DAC by measuring it with the ADS1015 and no more use of the second potentiometer)
  RTOS version : 2 tasks in // in the 2 cores with maximum priority for reading SiPM measurements in core 0 
                 with detection triggered by interrupt on pin 0 of the ESP32 and shared data protected by mutex.
               
  Muon detector Arduino Code  Using ESP32, 128x64 OLed screen, SD card, 3231 RTC, M8M GPS, ADS1015, BME280, DS18B20, BCD switch
  Program derived from "CosmicWatch Muons detector" project by Spencer Axani and adapted then improved for "CosmicSail 
  Astrolabe Expedition" by Yves Le Chevalier for coding and Christian Fromentin for the design of the electronic part, at My Human Kit.

  => This code is used to record data to the microSD card and display measures and data on Oled screen.
     It only uses one or two scintillators for its detections. (two scintillators for coincidence feature).
  NB : The size of the program exceed Arduino nano capacity Flash RAM or/and SRAM => and we use an ESP32 board 
       (Espressif ESP32 WROOM 32  also named "ESP32 Dev Module" for compilation under Arduino IDE 2)

  A new file is created each day with a name consisting of an "F" prefix followed by the current date.
  During all the day, the file is closed then reopened each hour to ensure its proper functioning.
  When reopening, records are appended to the file until the end of the hour, and so on...

  The RTC DS3132 may drift in time a very little bit. This is automatically checked and corrected if the GPS is picked up.
  Otherwise, to correct this drift, the push button set seconds on rtc to "30".  
  Just press it to synchronize the the displayed time with an external reference when this one reach 30 for seconds.
  This button is operational only when the Oled switch display the UTC date and time and when the GPS is or has been
  picked up for less than 7 days.

  All displays except alert or alarm messages are automatically turned off after 15 minutes of display. 
  You must then change the position switch to restore a display.

  All the SD card used must contain a file named "PARAM" which contains the following parameters: :
  detector name, date of implementation, name of the expedition or mission, name of the boarding ship.
  Each parameter is identified by a record code P1, P2, P3, P4.
  
+++> See the detailed documentation for more information.

  ESP32 Pinout :
          External comparator output pin 0       (digital input)   Trigger an interrupt
          Power SiMP (PWSIMP cmd)    pin 2       (analog output)   Powers up the SiPM
          Power led  (PWM cmd)       pin 4       (analog output)
          Sd card  (CS)              pin 5       (SPI) 
          I/O to drop input signal   pin 12      (digital output)  
          Signal for oscilloscope    pin 13      (digital output)   To view the timing of the measurements
          Commutateur BCD  (pin 1)   pin 14      (digital input)  activates bit1 (value 0001) = 1
          Commutateur BCD  (pin 2)   pin 15      (digital input)  activates bit2 (value 0010) = 2
          M8M GPS   (RXD)            pin 16      (UART2 serial port) For communication with GPS
          M8M GPS   (TXD)            pin 17      (UART2 serial port) For communication with GPS
          Sd card  (CLK)             pin 18      (SPI)
          Sd card  (MISO)            pin 19      (SPI) 
          ADS1015 (SDA)              pin 21      (I2C  addr=0x48)
          Oled Screen (SDA)          pin 21      (I2C  addr=0x3C)
          RTC DS3231  (SDA)          pin 21      (I2C addr=0x68)
          BME280      (SDA)          pin 21      (I2C addr=0x76)
          ADS1015 (SCL)              pin 22      (I2C  addr=0x48)
          Oled Screen (SCL)          pin 22      (I2C  addr=0x3C)
          RTC DS3231  (SCL)          pin 22      (I2C addr=0x68)
          BME280   (SCL)             pin 22      (I2C addr=0x76)
          Sd card  (MOSI)            pin 23      (SPI) 
          DAC output                 pin 25      (digital to analog output) Send a voltage corresponding to the background noise        
          Alarm red led              pin 26      (analog output)
          DS18B20 scintillator temp  pin 27      One wire input (whith external pullup through a 4.7kΩ resistor)
          Button (multipurpose)      pin 32      (digital input) PULLUP  Adjust RTC timer, close file, or ... 
          Commutateur BCD  (pin 3)   pin 33      (digital input)  activates bits 1 & 2 (value 0011) = 3
          Commutateur BCD  (pin 4)   pin 34      (digital input)  activates bit 4 (value 0100) = 4
          Coincicence switch         pin 35      coincidence detection flag (with external pullup)

  ADS1015 pinout :
        A0   Noise (electronically smoothed) for DAC calculation
        A1   Voltage given by SiPM (upon detection)
        A2   Voltage really send by the DAC to the comparator (because theoretical calculation of the voltage of the DAC according to the value sent is inaccurate)
        A3   Detection threshold adjusted by potentiometer
        
  BCD Switch :
        Pos0  no screen displayed  
        Pos1  Screen 1 = Display count and saved variables on last muon detection  
        Pos2  Screen 2 = Display UTC Date & Time
        Pos3  Screen 3 = Display SD and GPS data 
        Pos4  Screen 4 = Display the parameters of the parameter file
        Pos6  Screen 6 = List GPS frames on serial monitor
        pos9  Screen 9 = Display Instant detection variables and others data (test mode)    
       
*/

#include <U8g2lib.h>           // lib from oliver Kraus  v 2.33.15
U8G2_SH1106_128X64_NONAME_F_HW_I2C  u8g2(U8G2_R2/*, reset= U8X8_PIN_NONE */);
// screens list : https://github.com/olikraus/u8g2/wiki/u8g2setupcpp
// fonts list : https://github.com/olikraus/u8g2/wiki/fntlistall
#include "RTClib.h"            // lib from Adafruit  RTClib v 2.1.1
RTC_DS3231 myrtc;              // instance for the RTC clock
#include <SPI.h>               // lib from Adafruit  SPI v 2.0.0
#include "FS.h"                // lib from Adafruit  FS v 2.0.0
#include <SD.h>                // lib from Adafruit  SD v 2.0.0
File myFile;                   // instance for the file 
#include <Preferences.h>       // lib from Volodymyr Shymanskyy  Preferences v 2.0.0
Preferences detectorname;      // instance for the Preferences
#include <TinyGPS++.h>         // lib from Mikal Hart  TinyGPS++ v 1.0.3
TinyGPSPlus gps;               // instance for the GPS
#include <HardwareSerial.h>    // standard library
HardwareSerial SerialGPS(1);   // Hardware serial port #2
#include <Adafruit_BME280.h>   // lib from Adafruit  BME280 v 2.2.2 
Adafruit_BME280 BME280;        // instance for the BME280 
#include <ADS1X15.h>           // lib from Rob Tillaart  ADS1X15 v 0.3.9 
ADS1015 ADS(0x48);             // instance for the ADS1015 
#include "OneWire.h"           // lib from Jim Studt +...  OneWire v 2.3.7 
#include "DallasTemperature.h" //  lib from Mile Burton  DallasTemperature v 3.9.0 

// pins assignement :
#define COMPAR  0        // External Comparator input (interruption)
#define POWSIMP 2        // Powers up the SiPM using an optocoupler
#define LEDPOW  4        // Power led
#define SDSSPIN 5        // SD card CS/SS pin
#define EMPTCAP 12       // relay command to make the SiPM signal drop faster after measurements
#define OSCILLO 13       // ouput for oscilloscope
#define BCDSW4  14       // BCD switch pin 1 (with external pull-down)
#define BCDSW3  15       // BCD switch pin 1 (with external pull-down)
#define RXD2    16       // RXD serial port 2 for communication with GPS
#define TXD2    17       // TXD serial port 2 for communication with GPS
#define DAC     25       // DAC output sending a voltage corresponding to the background noise
#define LEDAL   26       // Alarm led (red)
#define SCITMP  27       // Scintillator temperature
#define BUTTON  32       // Button to adjust RTC timer or close file or ...
#define BCDSW2  33       // BCD switch pin 3 (with external pull-down)
#define BCDSW1  34       // BCD switch pin 4 (with external pull-down)
#define COINCI  35       // coincidence detection flag

OneWire oneWire(SCITMP); // setup oneWire instance
DallasTemperature DS18B20(&oneWire);

// initialize global variables
const String relnum = "Release 1.22";       // release number of the actual code
int powbrgt = 1;                            // Brightness of power led
float det_threshold;                        // default minimum detection threshold (in magnitude)
String detname;                             // Name of the detector read in Preferences
unsigned long timoldaff = 0L;               // timestamp of last Oled display
unsigned long timlastop = 0L;               // timestamp of last open file
char timestamp[20] = "";                    // String for record the formatted timestamp
unsigned long deadtime = 0L;                // total time between signals (millisec)
unsigned long deadaff = 0L;                 // total time displayed on screen (millis or minutes)
unsigned long deadtime_t0 = 0L;             // start time for dead time
long count = 0L;                            // A tally of the number of muon observed
long errcnt = 0L;                           // data access conflict count
unsigned int vadc0 = 0;                     // Voltage read on SiPM (mv)
unsigned int vadc = 0;                      // Memorized voltage read on SiPM (mv)
char filename[] = "/Fyymmdd.txt";           // filename created with today's date
String messerr = "";                        // error message for oled display
boolean aledstat = false;                   // error alarm led blinking indicator
int sdremain = 100;                         // % remaining space on SD card
double sdused = 0;                          // space used on SD card
boolean capalert = false;                   // alert indicator for remaining space on SD card
double sdcapacity = 0;                      // total capacity on SD card
double sdrealcap = 0;                       // available capacity at opening SD card
String recdata = "";                        // record on SD card
byte second = 30;                           // Value to adjust rtc time on top"30"
boolean dispok = false;                     // indicator for displaying on Oled screen
boolean oldisp = true;                      // old indicator for displaying on Oled screen
unsigned long timbou = 0;                   // timer to prevent button bounce
DateTime now;                               // actual date & time from RTC
char datew[12];                             // date formatting area
char timew[10];                             // time formatting area
int dayrec = 0;                             // day beeing recorded on SD
String longitude = "";                      // last measured longitude
String latitude = "";                       // last measured latitude
String memolongi = "";                      // last memorized longitude
String memolati = "";                       // last memorized latitude
int yeargps = -1;                           // gps data when functionnal
int monthgps = -1;                          // gps data when functionnal
int daygps = -1;                            // gps data when functionnal
int hourgps = -1;                           // gps data when functionnal
int minugps = -1;                           // gps data when functionnal
int secogps = -1;                           // gps data when functionnal
int atmopres = 0;                           // atmospheric pressure measured by BME280 expressed in hPa
float temperBME = 0;                        // temperature of the BME280 detector in degrees celsius
float temperSiPM = 0;                       // temperature of the SiPM detector in degrees celsius
float temper = 0;                           // average temperature of the 2 detectors in degrees celsius
boolean detect = false;                     // detection indicator
int noisea = 0;                             // sum of noise measures during last second (in magnitude not in volts)
int noiseb = 0;                             // sum of noise measures during previous second (in magnitude not in volts)
int nbnoisa = 0;                            // number of noise detections during last second
int nbnoisb = 0;                            // number of noise detections during previous second
int noise = 0;                              // Average noise during 2 seconds (in mv)
int noise1 = 0;                             // Average noise during 2 seconds (in magnitude)
boolean setdtrtc = false;                   // first date & time RTC setting indicator
float valdac = 0;                           // pseudo noise threshold in volts
int valdav = 0;                             // DAC threshold converted to mv.
int detfilter = 0;                          // low threshold detection to eliminate parasitics detections 
int nbelim = 0;                             // number of detections eliminated
boolean testmode = false;                   // tests indicator
char crapfile;                              // file creation or append indicator
unsigned long gpstime = 0L;                 // memorize last GPS update
unsigned int nbsat =0;                      // number of satellites
int bitr[4];                                // digits read on each 4 pins from BCD switch
int bcdvalue;                               // equivalent in decimal read on BCD switch
float coefx = 0;                            // noise correction multiplier (in magnitude 0 to 1351 = 2047/5*3,3)
float xcoefx = 0;                           // multiplication factor converted to coefficient 
boolean coincid = false;                    // coincidence detection flag 
String shipname = "";                       // Ship name from SD parameters (21 car max)
String impldat = "";                        // Implementation date (JJ/MM/AAAA)
String sponsor = "";                        // Sponsor/Donor name (21 car max)
int nbfiles = 0 ;                           // number of files on SD card
unsigned long timdisp = 0;                  // display start time (for automatic switch-off)
unsigned long timsync = 0;                  // last time check by gps
unsigned long timnois1 = 0L;                // timestamp 1 to wait for noise stabilization at startup
unsigned long timnois2 = 0L;                // timestamp 2 to wait for noise stabilization at startup
boolean dispend = false ;                   // indicator end of display over 15 minutes  
int swstat = 0 ;                            // switch state (position of the BCD switch)
char updatim[20] = "";                      // RTC updated time
boolean RTCbatempty = false ;               // indicator RTC battery is empty 
boolean affbat = false ;                    // indicator for blinking low RTC battery 

// initialize shared variables
int shvaldav = 0;                           // pseudo noise threshold converted to mv.
String shlatitude = "";                     // last measured latitude
String shlongitude = "";                    // last measured longitude
int shatmopres = 0;                         // atmospheric pressure measured by BME280 expressed in hPa
float shtemper = 0;                         // temperature of the detector in degrees celsius
double shsdused = 0;                        // space used on SD card

// function prototypes
void Blink_Alarm();
void Top_oscillo();
void DAC_calculation();
void BCDSwitchRead();
int ConvBin2Dec(int bit1, int bit2, int bit3, int bit4);
void Thresh_Detect();
void create_new_file(fs::FS &fs);
void reopen_file(fs::FS &fs);
void get_detector_name();
void count_nbfiles();
void read_param(fs::FS &fs);
void write_file_header();
void Switch_Oled();
void ErrorSD();
void Mess_Remove_SD();
void SD_capa_alert();
void DispRecData();
void OpeningScreen();
void DispDateTime();
void DispInstantCount();
void DispParam();
void DispSdGps();
void FeedGPS();
void GetGPSframe();
void Set_date_time();
void DispVarProg();
void ListGPSframe();
void RTClowBat();
void SharedData();
void Flash_Alarm();

SemaphoreHandle_t xBinarySemaphore = NULL;   // to handle interrupt on COMPAR pin
SemaphoreHandle_t xSema2 = NULL;             // to handle exclusive access of shared data

//------------------------------------------------------------------
void IRAM_ATTR detectinterrupt() {          // activate Task_Detect
  if (!detect) {
    detect = true;                          // detection indicator
      BaseType_t xHigherPriorityTaskWoken = pdFALSE;
      xSemaphoreGiveFromISR(xBinarySemaphore, &xHigherPriorityTaskWoken);
      if(xHigherPriorityTaskWoken != pdFALSE) portYIELD_FROM_ISR();
    //}
  }
}

//------------------------------------------------------------------
void Task_Detect(void *pvParameters) {      // detection task
  const char *pcTaskName = "Tack_Detect";
  UBaseType_t uxPriority;
  uxPriority = uxTaskPriorityGet(NULL);
  while(1)  {
    xSemaphoreTake(xBinarySemaphore, portMAX_DELAY);
    if (detect) {                             // verify detection flag set by the interrupt routine
      vadc0 = ADS.readADC(1);                 // SiPM measure in magnitude not in volts
      vadc = int(ADS.toVoltage(vadc0) * 1000); // Convert SiPM reading in mv   
      if (vadc > detfilter) {                 // check that it is not a parasitic detection
        Top_oscillo();
        digitalWrite(EMPTCAP,HIGH);           // Relay on to accelerate end of detection (empty the capacitor) 
        deadtime = (millis() - deadtime_t0);  // duration of dead time without activity above the detection threshold 
        deadtime_t0 = millis();               // starting time for deadtime 
        count++;       
        now = myrtc.now();   
        sprintf(timestamp, "%04d-%02d-%02d %02d:%02d:%02d", now.year(), now.month(), now.day(), now.hour(), now.minute(), now.second());      
        if( xSemaphoreTake(xSema2, 0) == pdPASS) {  // mutex semaphore used to keep exclusive acces to data     
          recdata = (String(timestamp) + ";" + vadc + ";" + shvaldav + ";" + deadtime);
          myFile.print(recdata);
          recdata = (";" + shlatitude + ";" + shlongitude + ";" + shatmopres + ";" + shtemper + "\n");        
          myFile.print(recdata); 
          shsdused = shsdused + recdata.length(); // Continuous calculation of occupied space
          xSemaphoreGive(xSema2);            // release exclusivity on shared data
        }
        else errcnt++;                       // shared data access conflict count
        ledcWrite(0, 200);                   // flash brievely led power as indicator detection
        vTaskDelay(pdMS_TO_TICKS(1));        // delay 1 ms
        ledcWrite(0, powbrgt);               // restore the power LED to its normal value  
        digitalWrite(EMPTCAP,LOW);           // restore relay off to allow next detection (fill the capacitor)
      }
      else nbelim++;                         // count of detections eliminated
      detect = false;                        // detection indicator off
      vTaskDelay(pdMS_TO_TICKS(1));          // delay 1 ms
    }  
  }
}
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
void loop()  {}   
//________________________________End_______________________________

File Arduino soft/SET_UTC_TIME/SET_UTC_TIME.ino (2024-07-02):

/* Muon detector set Date and Time in UTC time from connected computer on RTC DS3231 
   code written for Polar pod cosmic detection by YLC on 20/12/2022
   This programm must be executed only once before starting the detector.
*/

#include <U8g2lib.h>
U8G2_SSD1306_128X64_NONAME_F_HW_I2C u8g2(U8G2_R2/*, reset= U8X8_PIN_NONE */);  // to be modified according to screen
// screens list : https://github.com/olikraus/u8g2/wiki/u8g2setupcpp
// fonts list : https://github.com/olikraus/u8g2/wiki/fntlistall
#include "RTClib.h"
RTC_DS3231 myrtc;

int hourgap = 99;   // time difference between TU and time of the computer (number of hours in signed value)    
char datew[12]; 
char timew[10]; 
boolean rspd = false;      
int tuhour = 0;    // computed universal time hour
DateTime tutime;
DateTime now;

//--------------------------------------------------------------------------
void affdate() {
  now = myrtc.now();
  sprintf(datew, "%02d-%02d-%04d", now.day(), now.month(), now.year());  
  Serial.println("");
  Serial.println("------ Muon detector set UTC time ---------");           
  Serial.print("Date : ");  
  Serial.println(datew);   
}

//--------------------------------------------------------------------------
void afftime() {
  now = myrtc.now(); 
  sprintf(timew, "%02d:%02d:%02d", now.hour(), now.minute(), now.second());             
  Serial.println(timew);  
}

//------------------------------------------------------------------
void DispDateTime() {              // Date and time display  
  char datw[12]; 
  char heurw[10]; 
  now = myrtc.now();    
  u8g2.clearBuffer();
  u8g2.setFont(u8g2_font_crox3hb_tf );
  u8g2.setCursor(10,15);      
  sprintf(datw, "%02d-%02d-%04d", now.day(), now.month(), now.year());              
  u8g2.print(datw);    
  u8g2.setFont(u8g2_font_inb16_mf ); 
  u8g2.setCursor(0,55);       
  sprintf(heurw, "%02d:%02d:%02d", now.hour(), now.minute(), now.second());            
  u8g2.print(heurw);  
  u8g2.sendBuffer(); 
}   

//--------------------------------------------------------------------------
void setup () {
  Serial.begin(9600);
  u8g2.setI2CAddress(0x3C<<1);     // Modify I2C address + 1 bit offset for this Oled screen
  u8g2.begin();                    // screen initialization    
  u8g2.enableUTF8Print();          // allow accented characters               
  myrtc.begin();                   // start DS3231 RTC
  myrtc.adjust(DateTime(F(__DATE__), F(__TIME__)));   // set rtc date and time from computer 
  DispDateTime();
}
//--------------------------------------------------------------------------
void loop () {
  affdate(); 
  Serial.print("Local time is : ");  
  afftime();
  while (Serial.available()) { char inChar = Serial.read();}    // empty serial buffer
  Serial.println("Enter the signed number of hours difference between UTC and your time zone");  
  hourgap = 99;  
  while (hourgap == 99) {
    if (Serial.available())  {
      hourgap =  Serial.parseInt();      
    }        
  }   
  Serial.print("You answered ");  
  Serial.println(hourgap);
  if (!hourgap == 0) {   
    DateTime now = myrtc.now(); 
    tuhour = now.hour() + hourgap; 
    if ((tuhour > -1) && (tuhour < 24)) {
      DateTime tutime = DateTime(now.year(), now.month(), now.day(), tuhour, now.minute(), now.second());
      myrtc.adjust(tutime); 
      Serial.println("RTC changed to UTC"); 
      rspd = true;         
    }
    else {
      Serial.println("Please, make sure that we stay on the same date");  
      Serial.println("RTC time has not been changed !");  
    }
  }      
  else { 
    Serial.println("Nothing to change in the RTC."); 
  } 
  if (rspd) { 
    Serial.print("UTC (Universal Coordinated Time) is : ");      
    afftime(); 
     Serial.println("-------------------------------------");  
  }     
  while (1) {
    DispDateTime();
    delay(1000);   
  }
}
